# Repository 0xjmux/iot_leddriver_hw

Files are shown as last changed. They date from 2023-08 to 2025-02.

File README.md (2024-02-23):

# Spotify Neopixel Visualizer Hardware
Simple and compact ESP32-based WS2812B LED Strip Driver.   

<p align="center">
  
</p>

<!-- * Board firmware (in progress, not yet published) will be eventually available at [iot_leddriver_sw](https://github.com/0xjmux/iot_leddriver_sw). -->
* Origianlly planned to design my own firmware to integrate with the Spotify API Directly; but eventually switched to the much more featured combination of WLED + LEDFx. 
* Compatible with the popular [WLED](https://github.com/Aircoookie/WLED) firmware: just change the LED data pin to `GPIO21`. 
* (See [DEVELOPMENT-NOTES.md](DEVELOPMENT-NOTES.md) for full pinout and other information).

> [!WARNING]
> This was my first real PCB design, and I've improved a lot since I completed it. Take it (especially <=v2.2) with a grain of salt. 
 
### Features
* ESP32 based for low-cost IoT Capability, can use either `ESP32-S2-SOLO` (single core, cheaper) or `ESP32-S3-WROOM` (dual core). 
* Programmable over USB C, with Tag-Connect JTAG header for full debug capability. 
* Two ways to attach LED strip, either via pin header or with a strain relief. 
* Board designed to drive a 5m 60LED/m WS2812B strip with safety marign (see [DEVELOPMENT-NOTES.md](DEVELOPMENT-NOTES.md))
* Entirely LCSC BOM, designed for both hand and machine assembly. Able to be assembled by JLCPCB with low-cost components (almost all basic component BOM).

##### Optional Features and Mounting
* Designed to also be capable of driving 12V strips like the WS2811; only modification needed is changing the 5V overvoltage protection diodes (`D1`&`D2`, PN `SMF5V0A`) to 12V diodes (like `SMF12A`s)
* M2 mounting holes, various test pads, and an emergency UART header on the bottom. 
* Includes I2C breakout for optional addition of SSD1306 OLED.
* MEMS Microphone can optionally be added for live sound reactivity. 

#### Update 1/2024 - Now with a 3D Printable case!
* Check out [case/](./case/) for the 3D printable case I designed! This is the result of my first design using CAD in a very long time, and while it has some things I would change now I think it's still probably better published than not. 
* A PDF drawing of the case with dimensions can be found [here](case/iot_leddriver_drawing_v0.5.pdf).

<p align="center">
IRL picture of installation. Don't judge, it's in a really hard to reach place.
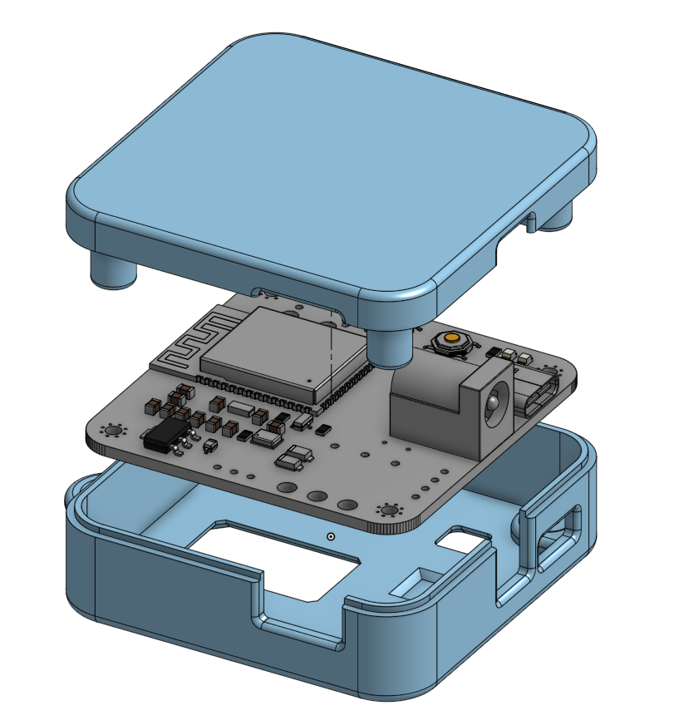
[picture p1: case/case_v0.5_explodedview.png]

</p>

## Notes and Usage
* Schematic, BOM, Gerbers, and all other files needed for production and assembly can be found attached to the latest [release!](https://github.com/0xjmux/iot_leddriver_hw/releases/latest)
  * This includes an interactive HTML BOM, which makes hand assembly much easier. 
* View current layout and schematic live on [KiCanvas](https://kicanvas.org/?github=https%3A%2F%2Fgithub.com%2F0xjmux%2Fiot_leddriver_hw%2Ftree%2Fmain%2FPCB)

<p align="center">
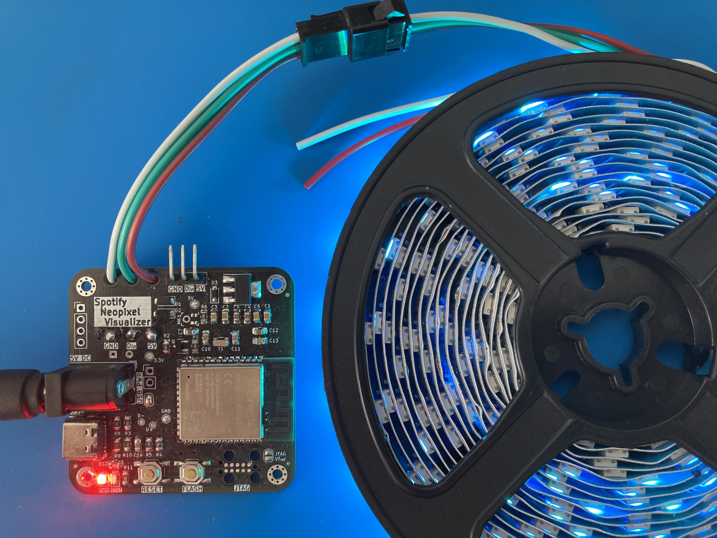
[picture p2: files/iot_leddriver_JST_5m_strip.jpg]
v2.1 showing LED strip standard JST connector connected to 5M WS2812B strip
  
<br>v2.1 showing LED strip standard JST connector connected to 5M WS2812B strip
</p>

## Versions
### V2.2 - QoL and Improvements for Production
* Mostly minor updates, to bring the board up to a more "production" ready state. Some modifications/fixes for small things found during manual assembly. 
* Power trace width from USB C port increased so short lengths of strip can be driven directly from USB.
* Traces cleaned up, PWR_LED can now be disconnected (if it's going to be deployed somewhere and the constant light is unwanted). USB_PWR jumpers removed. 
* BOM consolidation, some notes added to schematic, documentation improvements. 

<p align="center">
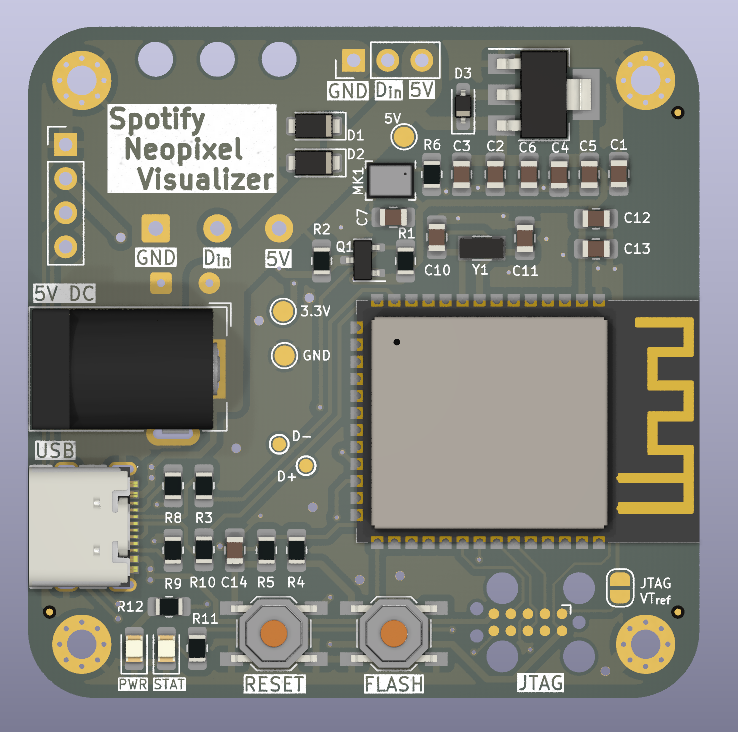
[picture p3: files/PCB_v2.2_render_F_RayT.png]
v2.2 PCB Render Front

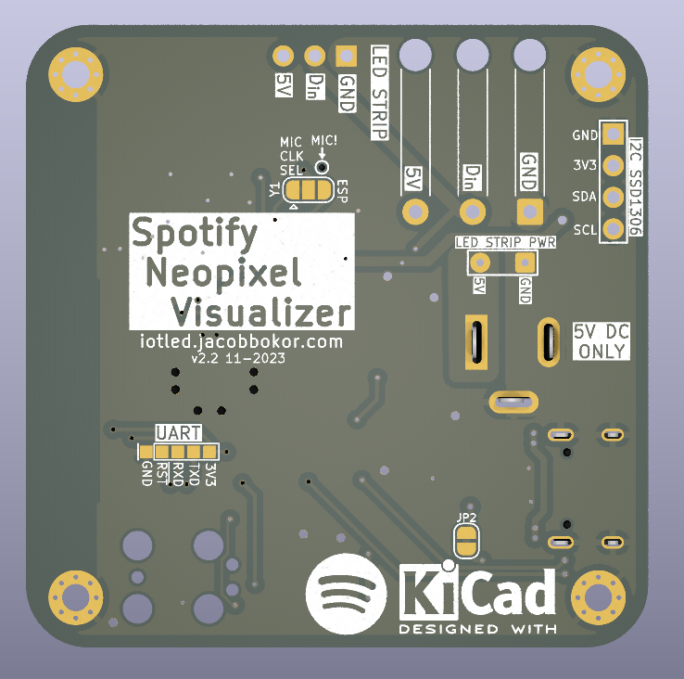
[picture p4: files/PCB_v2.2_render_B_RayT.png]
v2.2 PCB Render Back

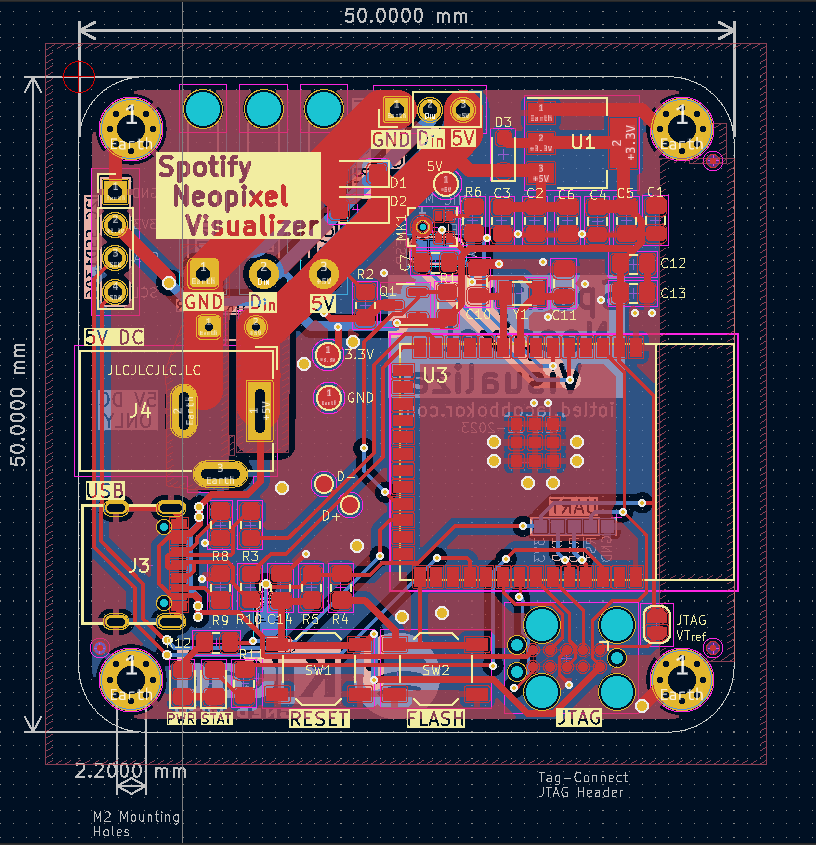
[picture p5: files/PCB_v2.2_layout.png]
v2.2 PCB Layout

</p>

### V2.1 - Hand Assembleable
* MCU originally selected for V2, the `ESP32-S2-MINI`, wasn't hand assemble-able; so it's been replaced with an `ESP32-S2-SOLO`. 
* Various small upgrades, including removal of non-necessary RC components, a mini UART header, and additional 5V power lines right next to the 2.1mm jack for strips with additional power wires. 
* The footprint and supporting components for a MEMS Microphone (`SPH0641LM4H-1`) added in case live sound reactivity is desired later on. 

<p align="center">
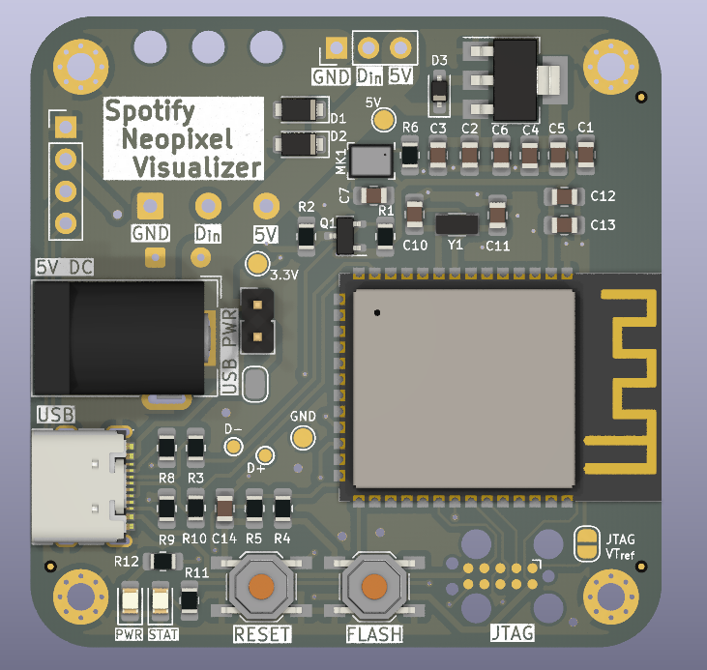
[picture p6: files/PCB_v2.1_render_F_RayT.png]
v2.1 PCB Render Front

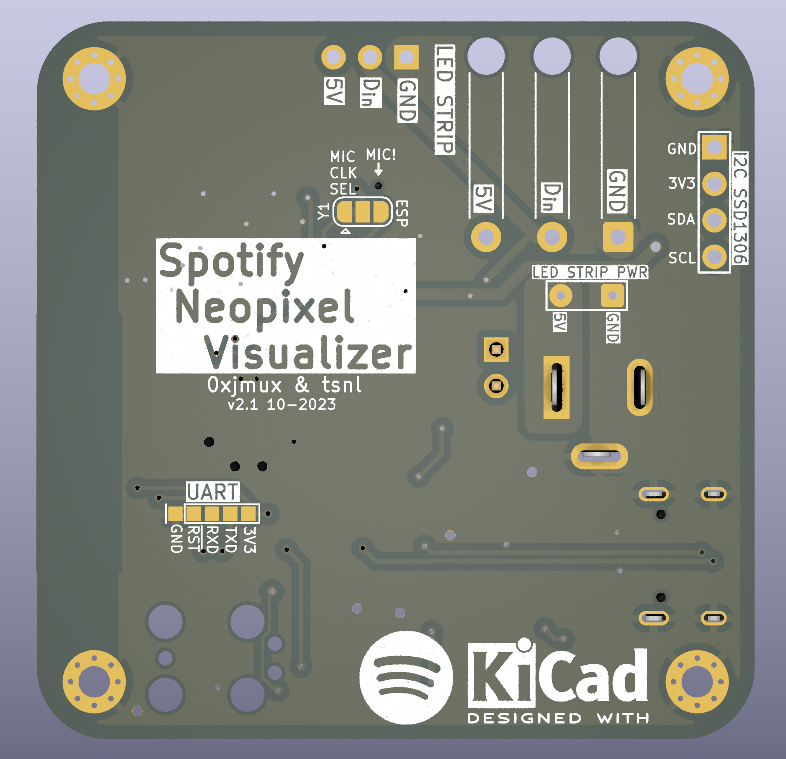
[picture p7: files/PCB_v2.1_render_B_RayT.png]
v2.1 PCB Render Back

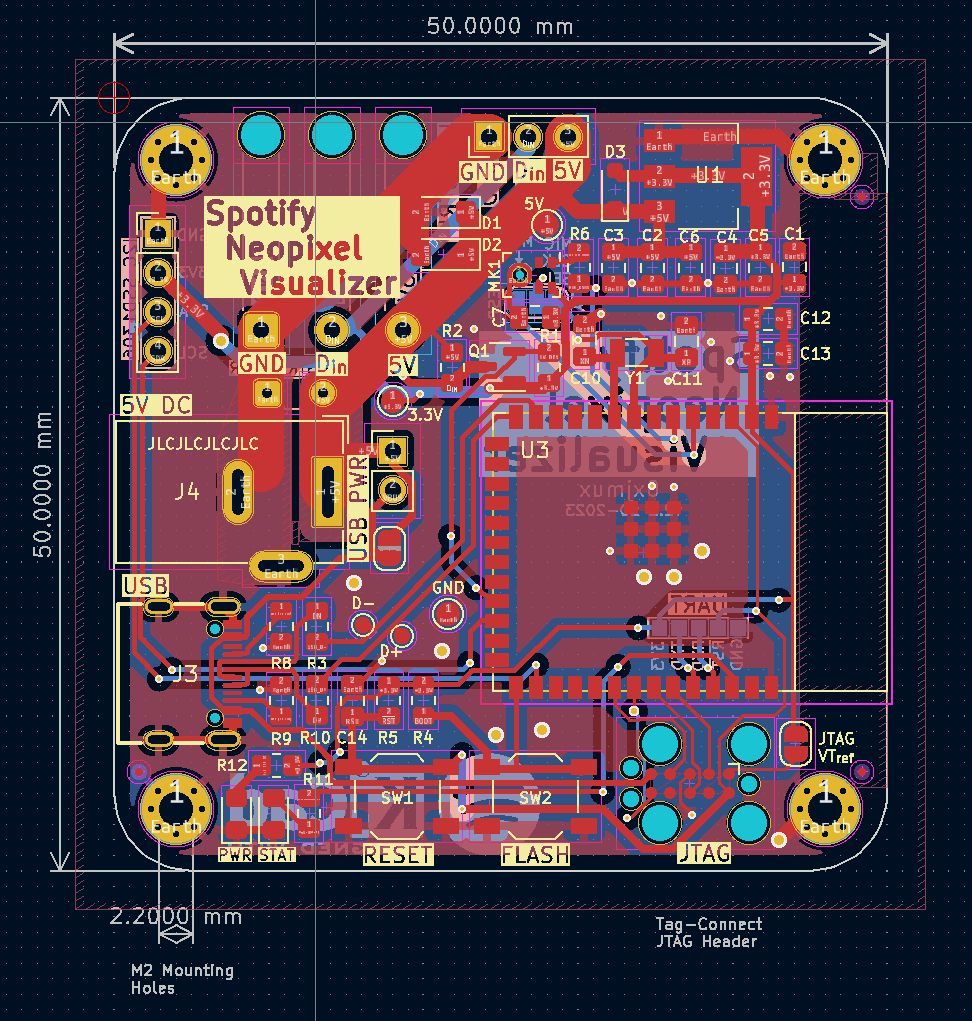
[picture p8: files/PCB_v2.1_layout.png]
v2.1 PCB Layout

</p>

### V2.0 - Complete redesign, now ESP32 Based
* Board upgraded to the `ESP32-S2-MINI-2-N4` for better compute capability, completely redesigned solely around the WS2812B.
* Most of the features listed above were introduced in this version.

<p align="center">
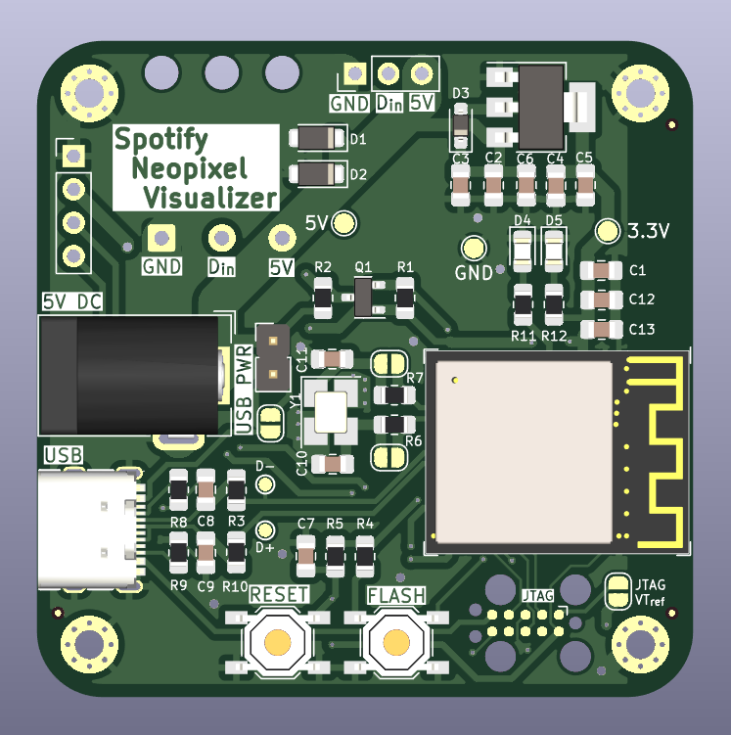
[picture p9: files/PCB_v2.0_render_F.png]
v2.0 PCB Render Front

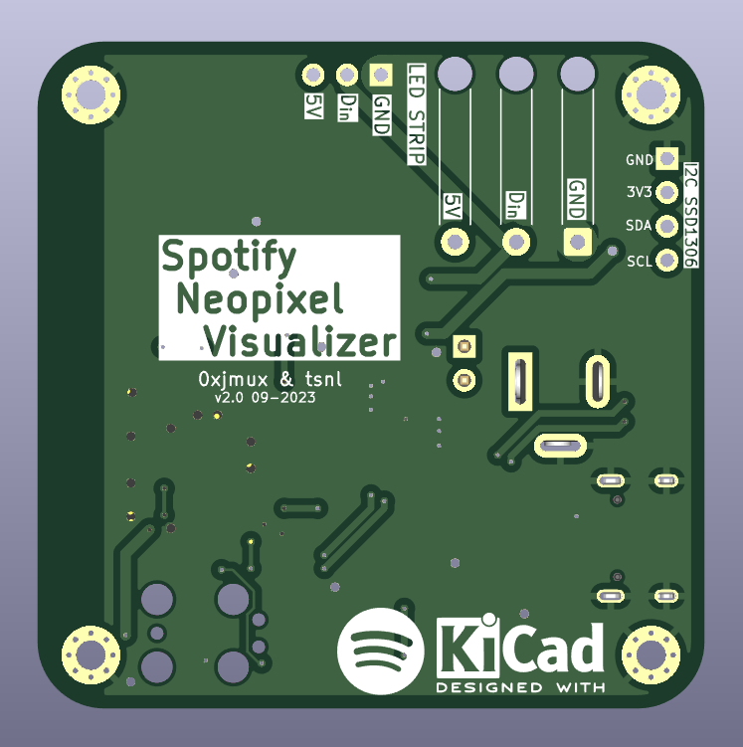
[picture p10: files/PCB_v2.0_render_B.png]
v2.0 PCB Render Back

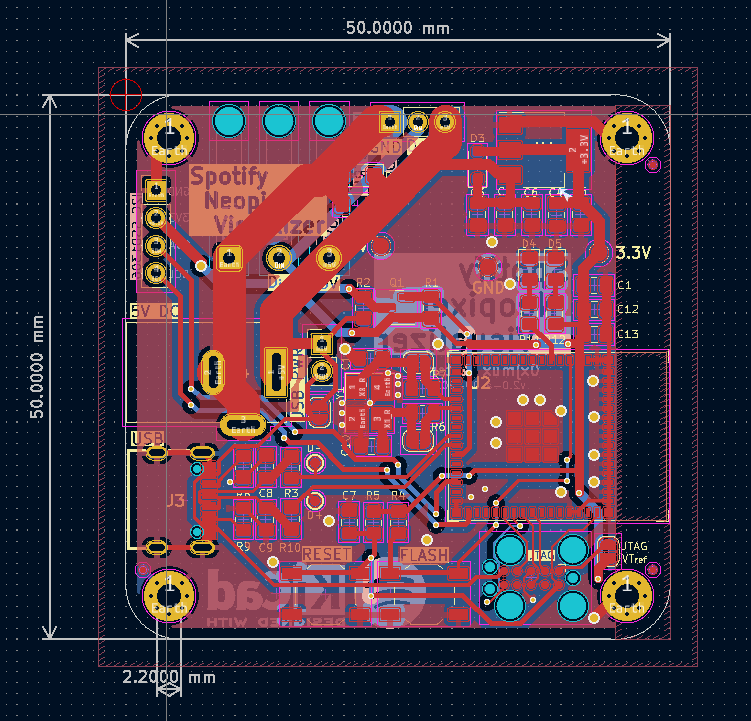
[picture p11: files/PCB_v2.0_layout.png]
v2.0 PCB Layout

</p>

---
### V1.0 Prototype
* [Link to v1.0 branch](https://github.com/0xjmux/iot_leddriver_hw/tree/v1.0)
* V1.0 was an IoT enabled LED strip driver using ESP8266 capable of using both WS2812B (Neopixel) and standard 5050 12V LED strips. Goal is to integrate with the spotify API to allow color changes in reaction to music. 
* V1 was never fully tested; right as v1.0 was ready my goal with the project shifted, and the ESP82666 just doesn't have enough compute for what I wanted to do. 
* If board will only be used in 5V (neopixel) mode, then the 3 `UMW30N06` Mosfets and 2 of the `MCP1416` mosfet drivers are not needed. Additionally, if the board will only be run in one mode then the unused 2.1mm jack does not need to be installed. 
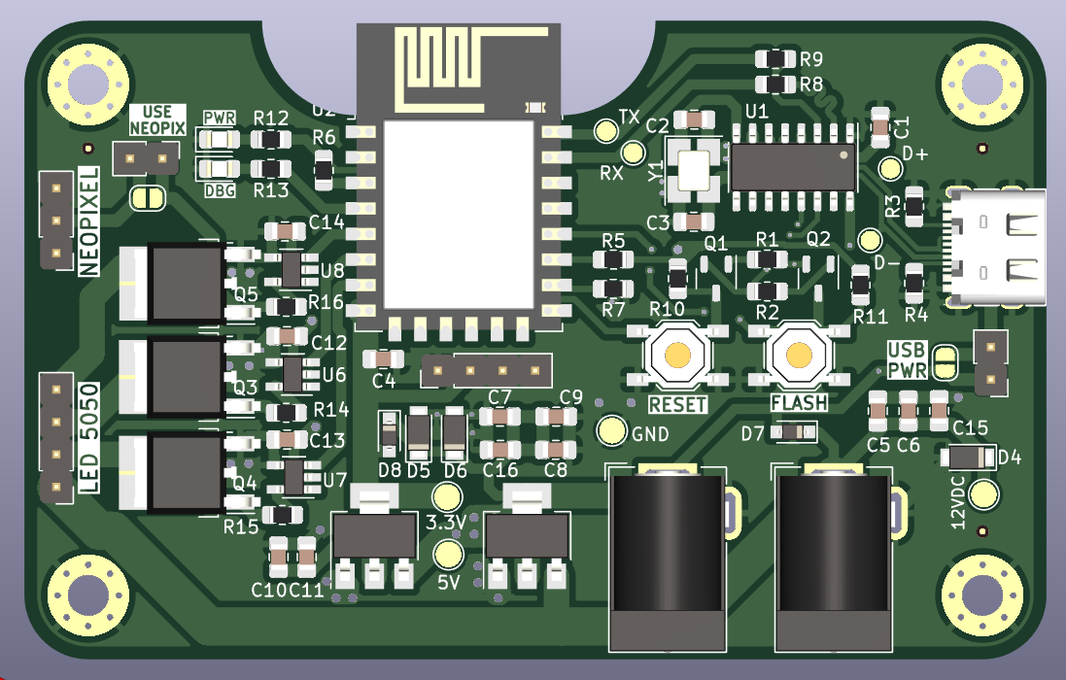
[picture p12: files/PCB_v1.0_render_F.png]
v1 PCB Render Front

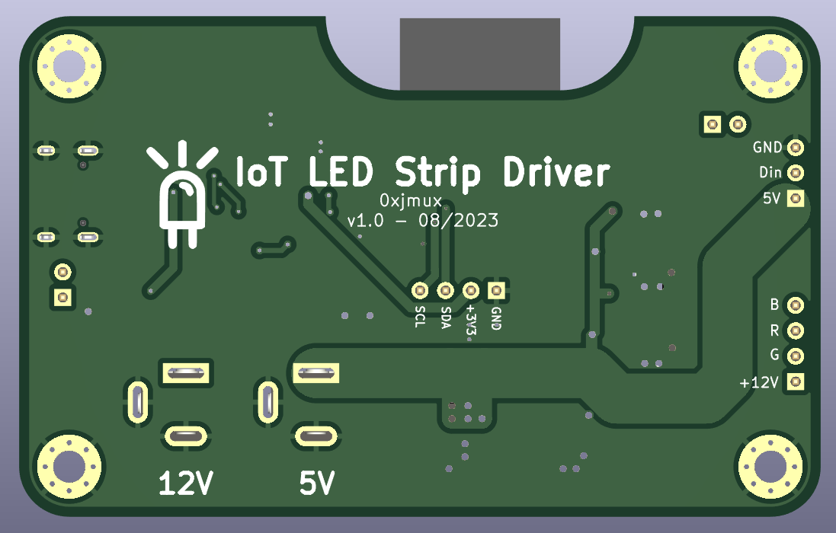
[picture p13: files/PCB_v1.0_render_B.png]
v1 PCB Render Back

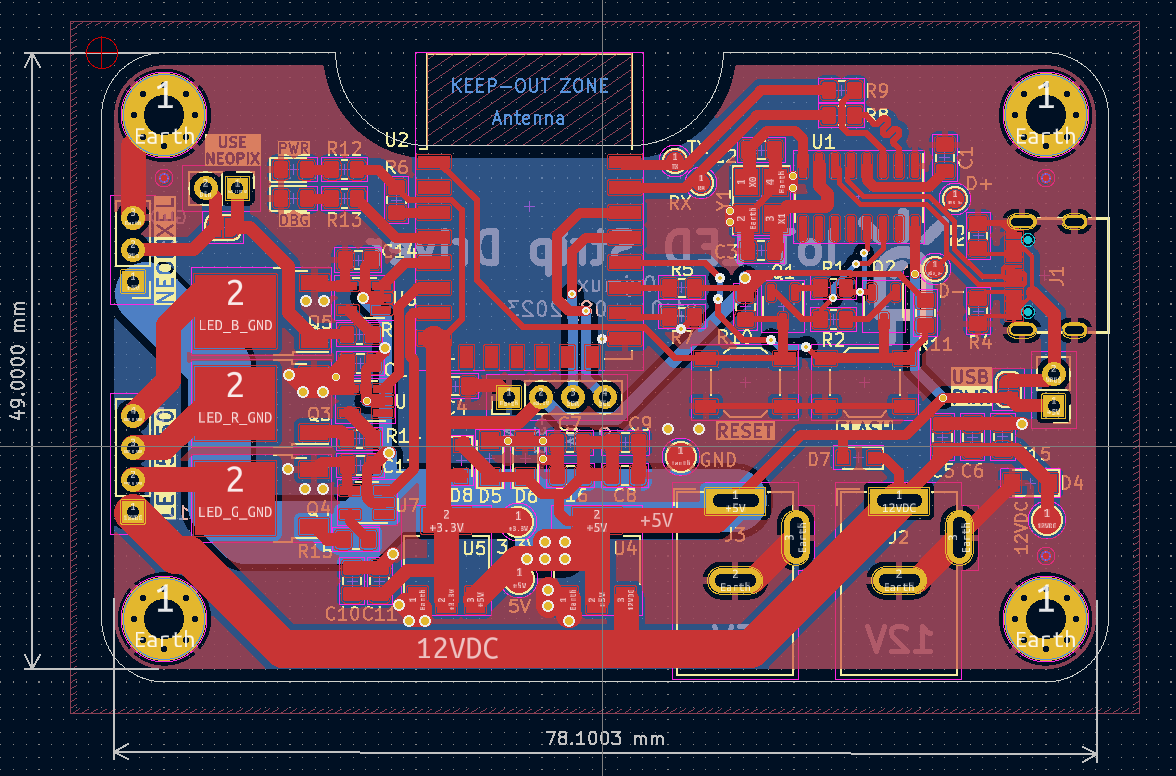
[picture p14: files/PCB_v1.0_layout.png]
v1 PCB Layout


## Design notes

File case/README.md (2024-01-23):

### Case info
* It's designed to be printed in PLA with 10% infill, and is held together by M2x8mm bolts. 
* The bolts are self tapping, and while I was originally planning on heat-set the self-tapped threads work so well that I'm just going to leave them as-is. 
* I included two different bottom models: One has a screwtab for easy mounting, and the other doesn't. You only need one. 

<p align="center">
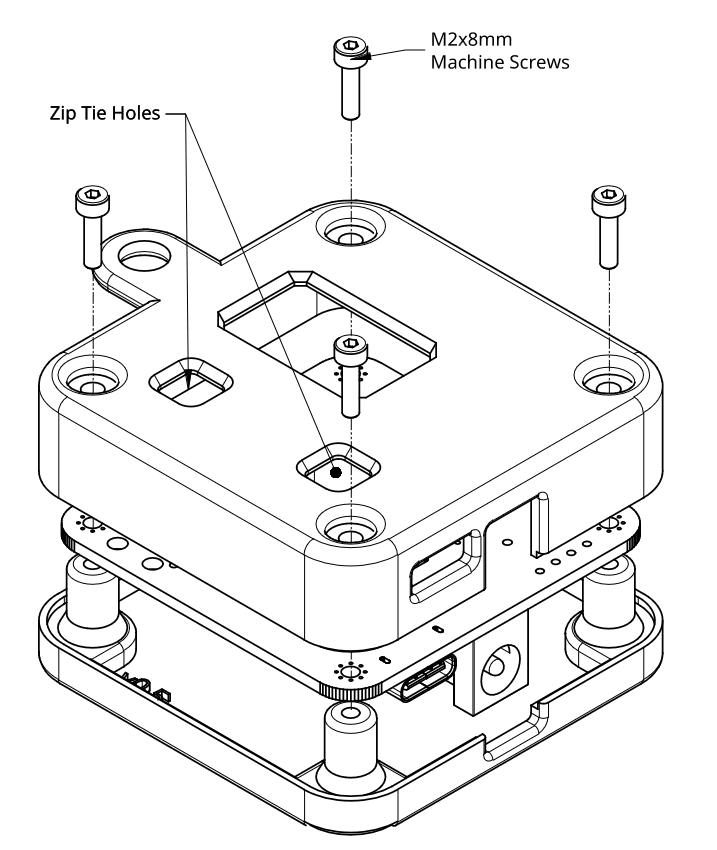
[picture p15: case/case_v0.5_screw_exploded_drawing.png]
  
  
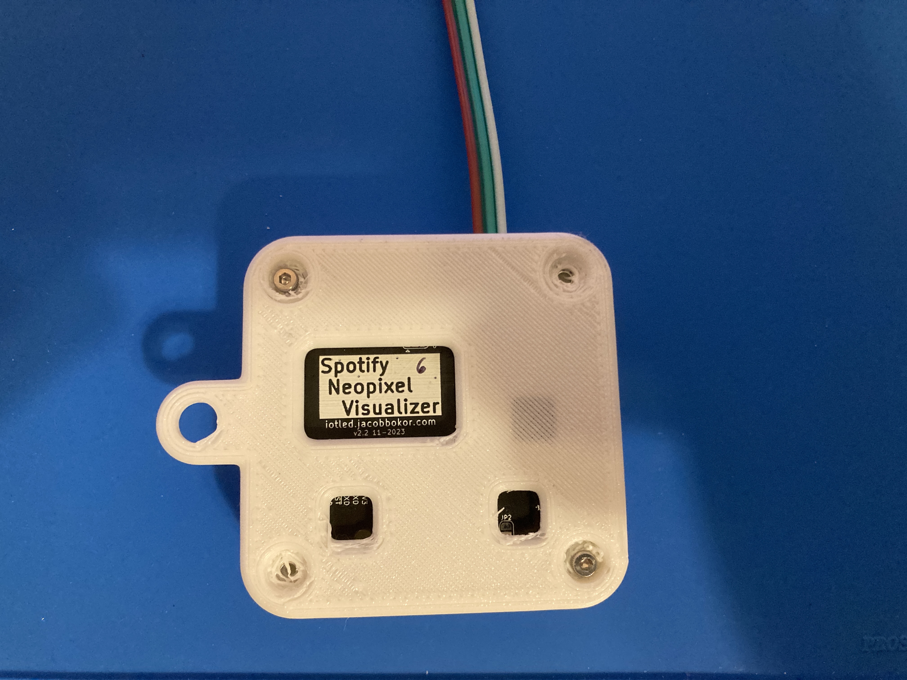
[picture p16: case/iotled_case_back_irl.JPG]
  
</p>

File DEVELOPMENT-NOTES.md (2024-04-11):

## Important Design Information
* All information about the board needed for development can be found attached tothe [latest release](https://github.com/0xjmux/iot_leddriver_hw/releases/latest)
#### Ideas/todo
* tindie listing with PCB and ESP-PROG adapter as like "wled developer kit?"
* 

## V2.2
* Current microcontroller is ESP32-S2-SOLO ([datasheet](https://www.espressif.com/sites/default/files/documentation/esp32-s2-solo-2_esp32-s2-solo-2u_datasheet_en.pdf))
* We're also attempting to use the [ESP32-S3-WROOM-2](https://www.espressif.com/sites/default/files/documentation/esp32-s3-wroom-2_datasheet_en.pdf) microcontroller during development, because of its dual-core capability. 
*  A MEMS Microphone, the `SPH0641LU4H-1`, can be optionally installed in case we later want to add live sound reactivity ([datasheet](https://www.knowles.com/docs/default-source/default-document-library/sph0641lm4h-1-datasheet-rev-f.pdf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) ).
#### Pinout

| GPIO PIN | Connected to |
|---|---|
| `GPIO21` | LED Strip D_in |
| `GPIO2`  | Status LED |
| `GPIO33` | I2C SDA |
| `GPIO35` | I2C SCL |
| `GPIO5`  | MEMS Mic Clock |
| `GPIO6`  | MEMS Mic Data  |

##### V2.2 breaking change:
* From v2.2, SCL has been moved to `GPIO37`. This was because on the WROOM, `GPIO35` is not present (and is an NC pin). 

#### Hardware Limitations
* Trace width and vias for power delivery from DC jack to LED Strip Power lines calculated to handle 12A with ΔT rise of <10°C. 
* Maximum draw of a 5M 60 LED/m WS2812B strip (all white at maximum brightness) is 12A @ 5V. Anything longer than that and you start seeing the brightness drop due to the resistance of the traces inside the strip, so it is unlikely this design limit will be exceeded. 

### ESP32-S2-SOLO Information
* [ESP32-S2-SOLO-2 Datasheet pdf](https://www.espressif.com/sites/default/files/documentation/esp32-s2-solo-2_esp32-s2-solo-2u_datasheet_en.pdf)
* [esp32-s2_hardware_design_guidelines_en.pdf](https://www.espressif.com/sites/default/files/documentation/esp32-s2_hardware_design_guidelines_en.pdf)
* [esp32-s2_technical_reference_manual_en.pdf](https://www.espressif.com/sites/default/files/documentation/esp32-s2_technical_reference_manual_en.pdf)

### ESP32-S3-WROOM Information
What we're using during development, since it's the most powerful ESP32 chip currently available + is dual core. If we don't end up needing the second core, software will be able to be compiled for S2. 
* [ESP32-S3-WROOM-2 Datasheet pdf](https://www.espressif.com/sites/default/files/documentation/esp32-s3-wroom-2_datasheet_en.pdf)

### ESP32 pin information
* [ESP32 Pinout Reference: Which GPIO pins should you use? | Random Nerd Tutorials](https://randomnerdtutorials.com/esp32-pinout-reference-gpios/)

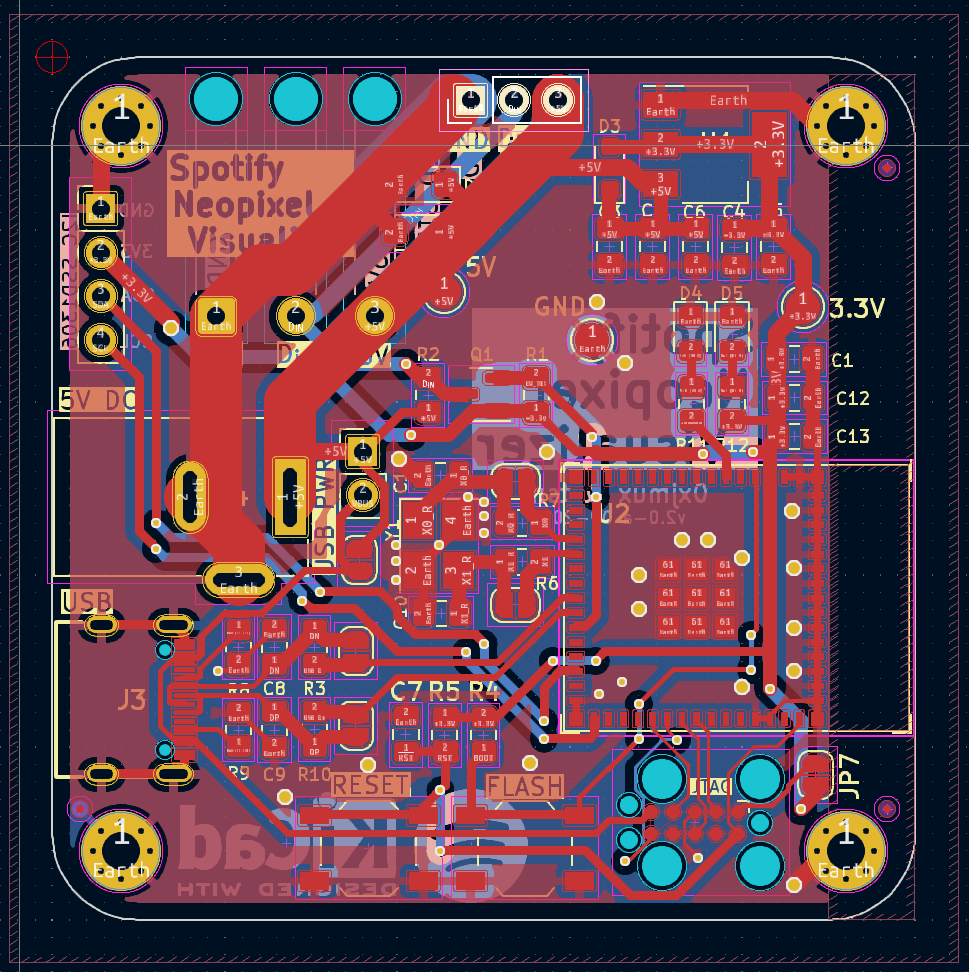
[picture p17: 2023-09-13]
files/PCB_v1.9.1-a_layout.png

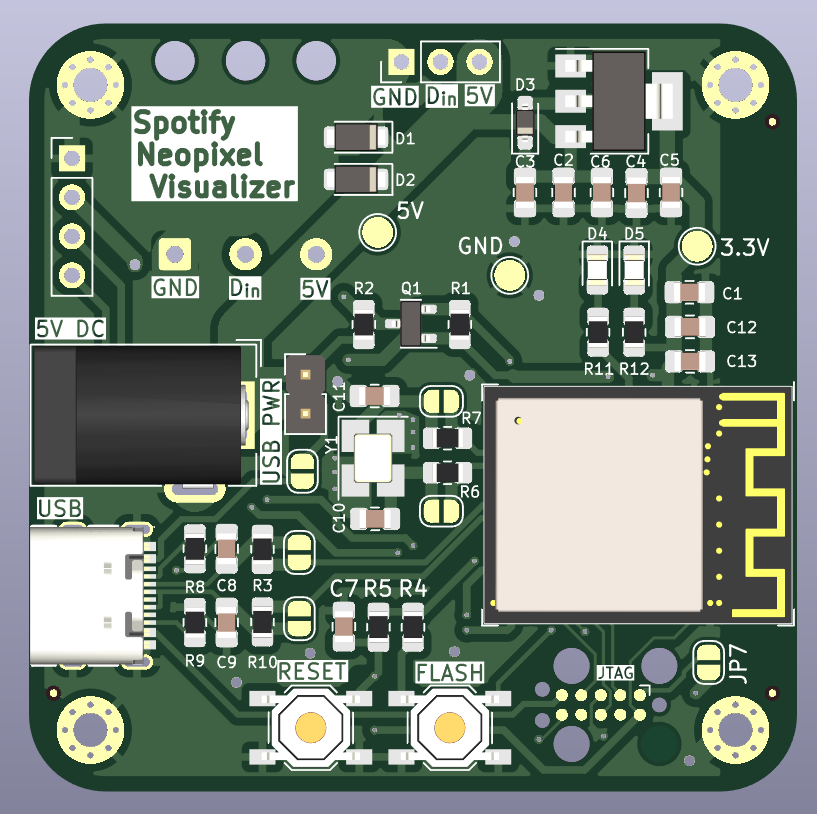
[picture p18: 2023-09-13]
files/PCB_v1.9.1-a_render_F.png

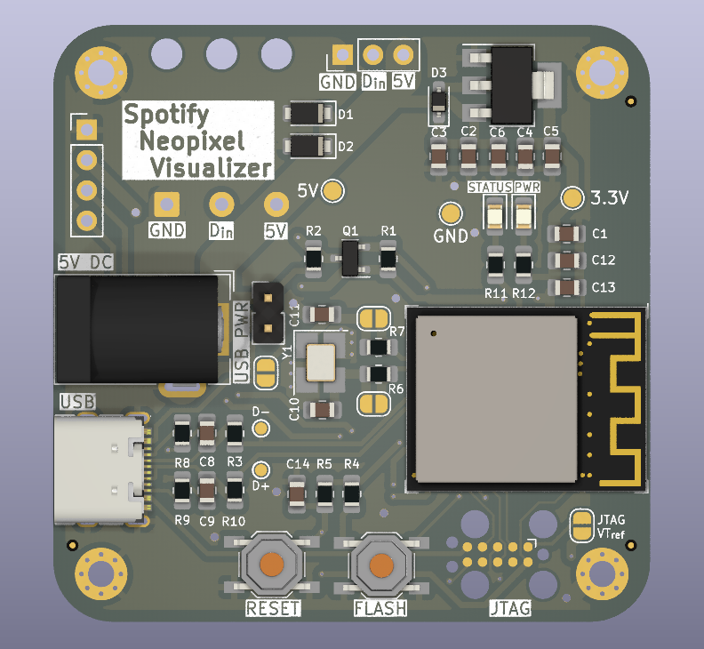
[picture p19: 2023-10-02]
files/PCB_v2.0.1-render_F_RayT.png

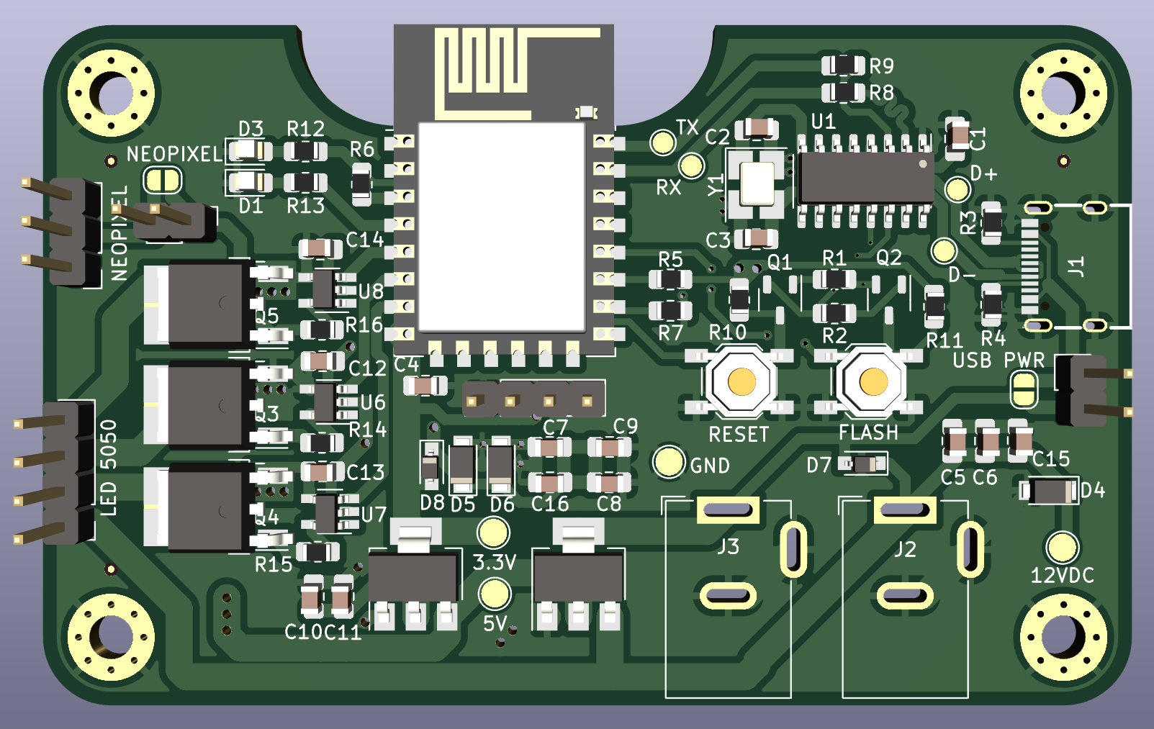
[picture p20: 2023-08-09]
files/PCB_v0.9.1_render_F.png

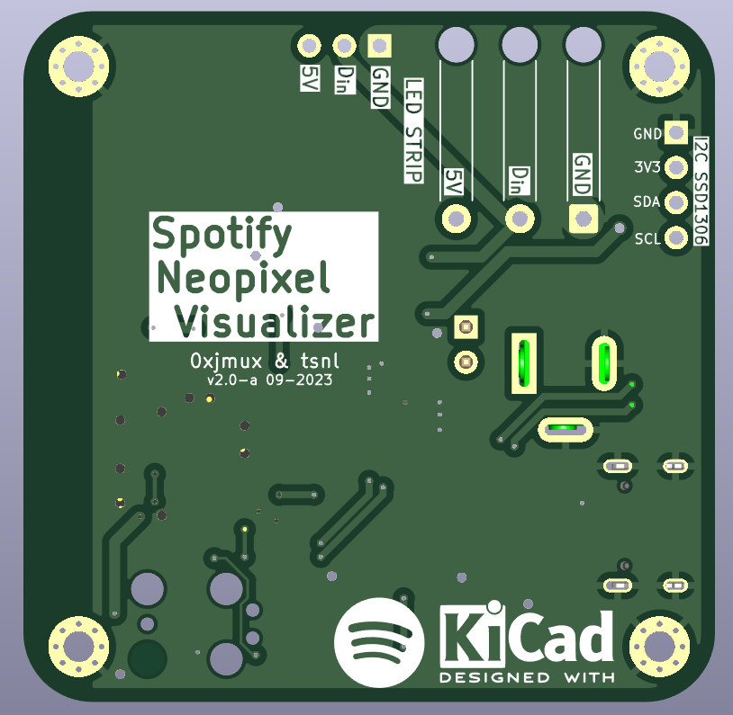
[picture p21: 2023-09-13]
files/PCB_v1.9.1-a_render_B.png

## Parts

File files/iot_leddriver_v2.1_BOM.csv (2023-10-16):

Source: | /home/jmux/Github/spotify-iot-led-driver/iot_leddriver_hw/iot_led_strip_pcb.kicad_sch
Date: | Sun 15 Oct 2023 09:47:59 PM PDT
Tool: | Eeschema 7.0.7-2.fc37
Generator: | /usr/share/kicad/plugins/bom_csv_grouped_by_value.py
Component Count: | 37
Collated Components:
Item | Qty | Reference(s) | Value | LibPart | Footprint | Datasheet | DNP | Description | LCSC | Sim.Device | Sim.Params | Sim.Pins | Sim.Type | Vendor
1 | 5 | C1, C2, C3, C5, C13 | 10uF | Device:C | Capacitor_SMD:C_0805_2012Metric_Pad1.18x1.45mm_HandSolder | ~ |  | 16V 10uF 0805 Ceramic Capacitor SMD | C15850 |  |  |  |  | https://www.lcsc.com/product-detail/Multilayer-Ceramic-Capacitors-MLCC-SMD-SMT_Murata-Electronics-GRM21BR61C106KE15L_C77075.html
2 | 5 | C4, C6, C7, C12, C14 | 100nF | Device:C | Capacitor_SMD:C_0805_2012Metric_Pad1.18x1.45mm_HandSolder | ~ |  | 100nF 50V X7R ±10% 0805 Ceramic Cap SMD | C49678 |  |  |  |  | https://jlcpcb.com/partdetail/Yageo-CC0805KRX7R9BB104/C49678
3 | 2 | C10, C11 | 22pF | Device:C | Capacitor_SMD:C_0805_2012Metric_Pad1.18x1.45mm_HandSolder | ~ |  | 22pF 50V ±5% 0805 Multilayer Ceramic Capacitors | C1804 |  |  |  |  | https://www.lcsc.com/product-detail/Multilayer-Ceramic-Capacitors-MLCC-SMD-SMT_FH-Guangdong-Fenghua-Advanced-Tech-0805CG220J500NT_C24658.html
4 | 2 | D1, D2 | SMF5V0A | Diode:SMF5V0A | Diode_SMD:D_SMF | https://www.vishay.com/doc?85881 |  | 9.2V 6.4V 5V SMF TVS | C1972946
5 | 1 | D3 | 1N5819WS | Device:D_Schottky | Diode_SMD:D_SOD-323_HandSoldering | ~ |  | 40V 600mV@1A 1A SOD-323 Schottky Barrier Diode | C191023
6 | 1 | D4 | STAT | Device:LED | LED_SMD:LED_0805_2012Metric_Pad1.15x1.40mm_HandSolder | ~ |  | Blue (red linked) 0805 Light Emitting Diode | C84256 |  |  |  |  | https://www.lcsc.com/product-detail/Light-Emitting-Diodes-LED_Foshan-NationStar-Optoelectronics-NCD1206B1_C130717.html
7 | 1 | D5 | PWR | Device:LED | LED_SMD:LED_0805_2012Metric_Pad1.15x1.40mm_HandSolder | ~ |  | Red 0805 Light Emitting Diode | C84256 |  |  |  |  | https://www.lcsc.com/product-detail/Light-Emitting-Diodes-LED_Foshan-NationStar-Optoelectronics-NCD1206B1_C130717.html
8 | 1 | J3 | GT-USB-7010ASV | gt-usb_lib:GT-USB-7010ASV | footprint:USB-C-SMD_G-SWITCH_GT-USB-7010ASV | https://atta.szlcsc.com/upload/public/pdf/source/20220407/8043DBBC37E1BDE9D4FD36EE7A4A9BB9.pdf |  |  | C2988369 |  |  |  |  | https://www.lcsc.com/product-detail/USB-Connectors_G-Switch-GT-USB-7010ASV_C2988369.html
9 | 1 | J4 | Barrel_Jack_Switch_Pin3Ring | Connector:Barrel_Jack_Switch_Pin3Ring | Connector_BarrelJack:BarrelJack_Wuerth_6941xx301002 | ~ |  |  |  | V | dc=5 | 1=+ 2=- | DC
10 | 1 | MK1 | SPH0641LU4H-1 | Sensor_Audio:SPH0641LU4H-1 | Sensor_Audio:Knowles_LGA-5_3.5x2.65mm | https://www.knowles.com/docs/default-source/model-downloads/sph0641lu4h-1-revb.pdf |  | MEMS Microphone. COVER HOLE DURING ASSEMBLY!!! | C5454543 |  |  |  |  | https://www.lcsc.com/product-detail/MEMS-Microphones_Knowles-SPH0641LM4H-1-8_C5454543.html
11 | 1 | Q1 | BSS138 | Transistor_FET:BSS138 | Package_TO_SOT_SMD:SOT-23 | https://www.onsemi.com/pub/Collateral/BSS138-D.PDF |  | 50V 220mA 3.5Ω@10V,220mA 360mW N Channel SOT-23(TO-236) MOSFET | C358381 |  |  |  |  | https://jlcpcb.com/partdetail/Foshan_Blue_RocketElec-BSS138/C358381
12 | 4 | R1, R2, R4, R5 | 10k | Device:R_US | Resistor_SMD:R_0805_2012Metric_Pad1.20x1.40mm_HandSolder | ~ |  | 10kΩ 0805 Chip Resistor | C17414 |  |  |  |  | https://www.lcsc.com/product-detail/Chip-Resistor-Surface-Mount_FOJAN-FRQ0805F1002TS_C5159708.html
13 | 2 | R3, R10 | 27R | Device:R_US | Resistor_SMD:R_0805_2012Metric_Pad1.20x1.40mm_HandSolder | ~ |  | 27Ω 0805 125mW Chip Resistor | C17594 |  |  |  |  | https://www.lcsc.com/product-detail/Chip-Resistor-Surface-Mount_UNI-ROYAL-Uniroyal-Elec-0805W8F270JT5E_C17594.html
14 | 3 | R6, R11, R12 | 100 | Device:R_US | Resistor_SMD:R_0805_2012Metric_Pad1.20x1.40mm_HandSolder | ~ |  | 100Ω 0805 125mW Chip Resistor | C17408 |  |  |  |  | https://jlcpcb.com/partdetail/18096-0805W8F1000T5E/C17408
15 | 2 | R8, R9 | 5.1k | Device:R_US | Resistor_SMD:R_0805_2012Metric_Pad1.20x1.40mm_HandSolder | ~ |  | 5.1kΩ 0805 125mW Chip Resistor | C27834 |  |  |  |  | https://www.lcsc.com/product-detail/Chip-Resistor-Surface-Mount_VO-0805-5-470_C2889528.html
16 | 1 | SW1 | RESET | C5117870_lib:GT-TC060A-H025-L1 | Button_Switch_SMD:SW_SPST_TL3342 | https://item.szlcsc.com/902766.html |  |  | C318884 |  |  |  |  | https://www.lcsc.com/product-detail/Tactile-Switches_G-Switch-GT-TC060A-H025-L1_C5117870.html
17 | 1 | SW2 | FLASH | C5117870_lib:GT-TC060A-H025-L1 | Button_Switch_SMD:SW_SPST_TL3342 | https://item.szlcsc.com/902766.html |  |  | C318884 |  |  |  |  | https://www.lcsc.com/product-detail/Tactile-Switches_G-Switch-GT-TC060A-H025-L1_C5117870.html
18 | 1 | U1 | AMS1117-3.3 | Regulator_Linear:AMS1117-3.3 | Package_TO_SOT_SMD:SOT-223-3_TabPin2 | http://www.advanced-monolithic.com/pdf/ds1117.pdf |  |  | C6186 |  |  |  |  | https://www.lcsc.com/product-detail/Linear-span-style-background-color-ff0-Voltage-span-Regulators-LDO_UMW-Youtai-Semiconductor-Co-Ltd-AMS1117-3-3_C347222.html
19 | 1 | U3 | ESP32-S2-SOLO | PCM_Espressif:ESP32-S2-SOLO | Espressif:ESP32-S2-SOLO | https://www.espressif.com/sites/default/files/documentation/esp32-s2-solo_esp32-s2-solo-u_datasheet_en.pdf |  |  | C3040594
20 | 1 | Y1 | Crystal 32kHz | Device:Crystal | Crystal:Crystal_SMD_3215-2Pin_3.2x1.5mm | ~ |  |  | C97606

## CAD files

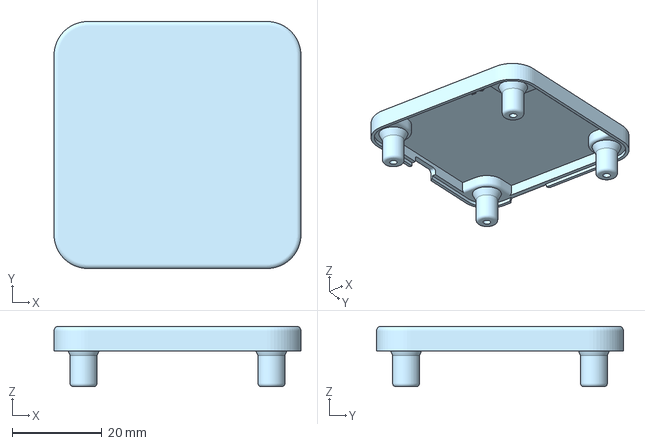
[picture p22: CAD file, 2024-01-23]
case/iot_leddriver_top_v0.5.3mf
55.2 x 55.2 x 13.5 mm

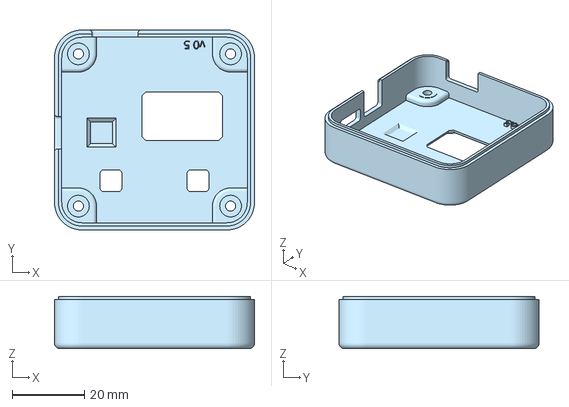
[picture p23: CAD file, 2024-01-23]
case/iot_leddriver_bot_v0.5.3mf
55.2 x 55.2 x 14.4 mm

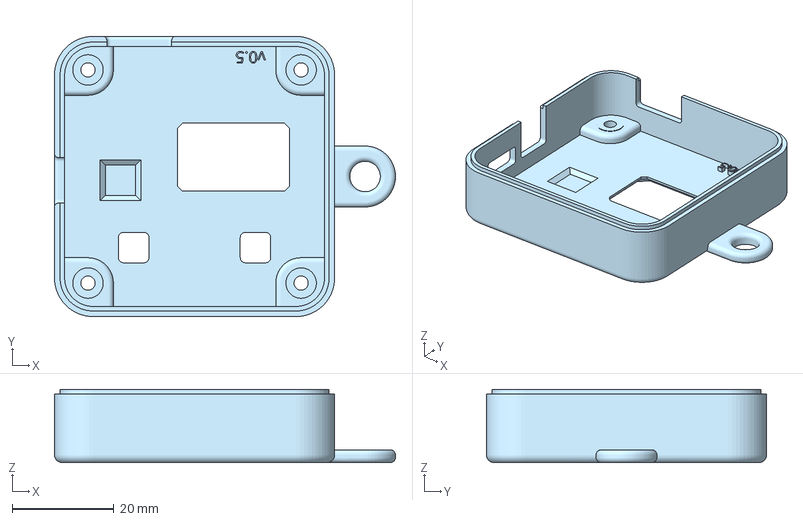
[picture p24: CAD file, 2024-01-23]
case/iot_leddriver_bot_screwtab_v0.5.3mf
67.2 x 55.2 x 14.4 mm

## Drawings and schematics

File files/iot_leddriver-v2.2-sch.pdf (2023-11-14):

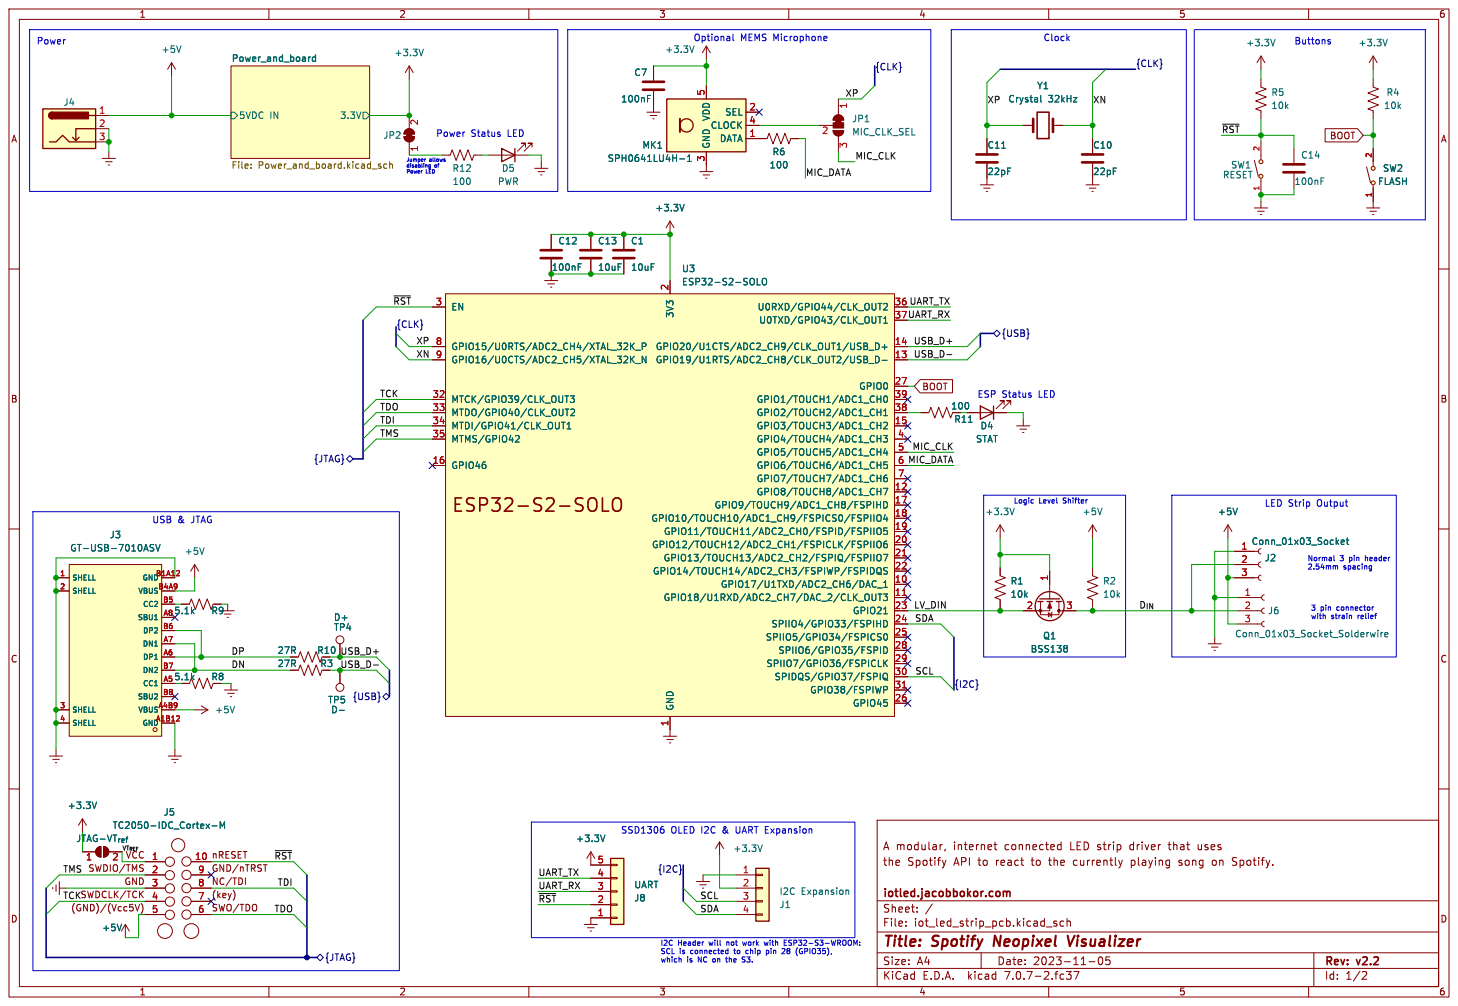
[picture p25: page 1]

2 GPIO12/TOUCH12/ADC2_CH1/FSPICLK/FSPIIO6 20 GPIO13/TOUCH13/ADC2_CH2/FSPIQ/FSPIIO7 21 GPIO14/TOUCH14/ADC2_CH3/FSPIWP/FSPIDQS 22 GPIO21 23 SPIIO4/GPIO33/FSPIHD 24 SPIIO5/GPIO34/FSPICS0 25 GPIO45 26 GPIO0 27 SPIIO6/GPIO35/FSPID 28 SPIIO7/GPIO36/FSPICLK 29 EN 3 SPIDQS/GPIO37/FSPIQ 30 GPIO38/FSPIWP 31 MTCK/GPIO39/CLK_OUT3 32 MTDO/GPIO40/CLK_OUT2 33 MTDI/GPIO41/CLK_OUT1 34 MTMS/GPIO42 35 U0RXD/GPIO44/CLK_OUT2 36 U0TXD/GPIO43/CLK_OUT1 37 GPIO2/TOUCH2/ADC1_CH1 38 GPIO1/TOUCH1/ADC1_CH0 39 GPIO4/TOUCH4/ADC1_CH3 4 GPIO5/TOUCH5/ADC1_CH4 5 GPIO6/TOUCH6/ADC1_CH5 6 GPIO7/TOUCH7/ADC1_CH6 7 GPIO15/U0RTS/ADC2_CH4/XTAL_32K_P 8 GPIO16/U0CTS/ADC2_CH5/XTAL_32K_N 9 U3ESP32-S2-SOLO

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

3 pin connector with strain relief USB & JTAG

iotled.jacobbokor.com
Id: 1/2 Title: Spotify Neopixel Visualizer File: iot_led_strip_pcb.kicad_sch Sheet: /

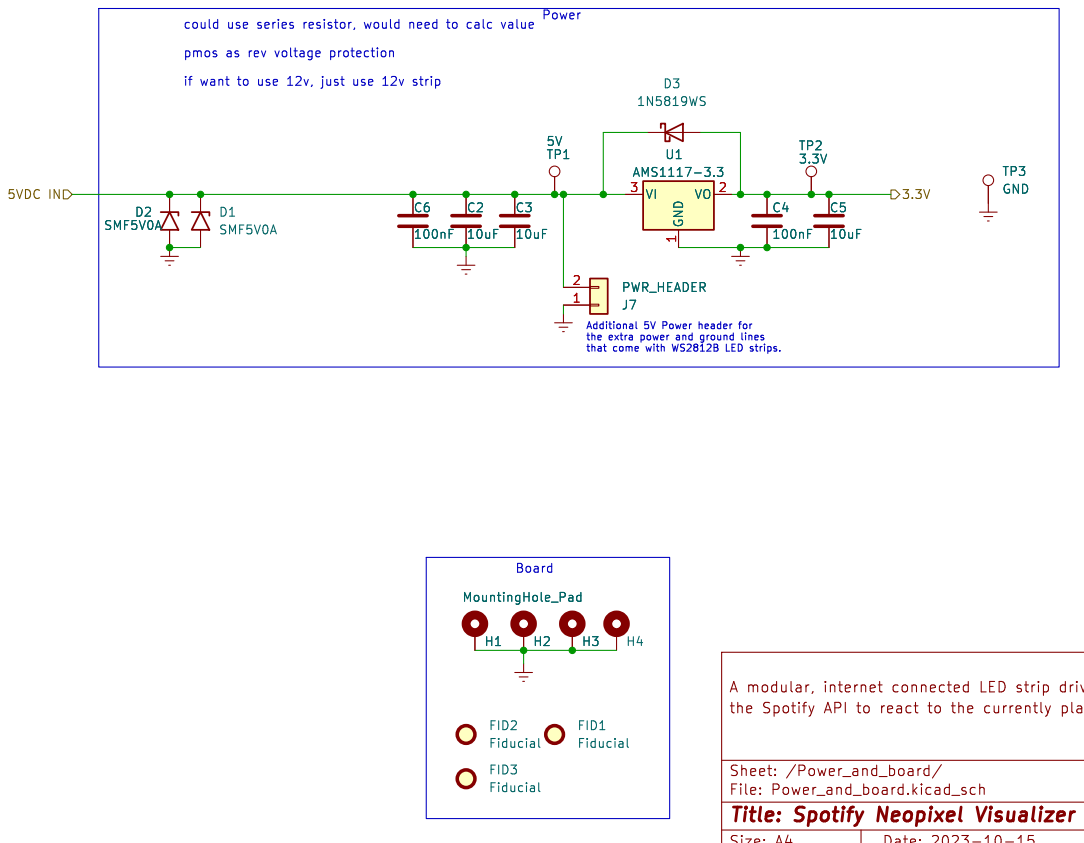
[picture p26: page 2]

pmos as rev voltage protection

1 VO 2 VI 3 U1 AMS1117-3.3 FID2 Fiducial H1 H3 MountingHole_Pad H2 H4 FID1 Fiducial C4

that come with WS2812B LED strips. C3

the extra power and ground lines

Id: 2/2 Title: Spotify Neopixel Visualizer File: Power_and_board.kicad_sch Sheet: /Power_and_board/

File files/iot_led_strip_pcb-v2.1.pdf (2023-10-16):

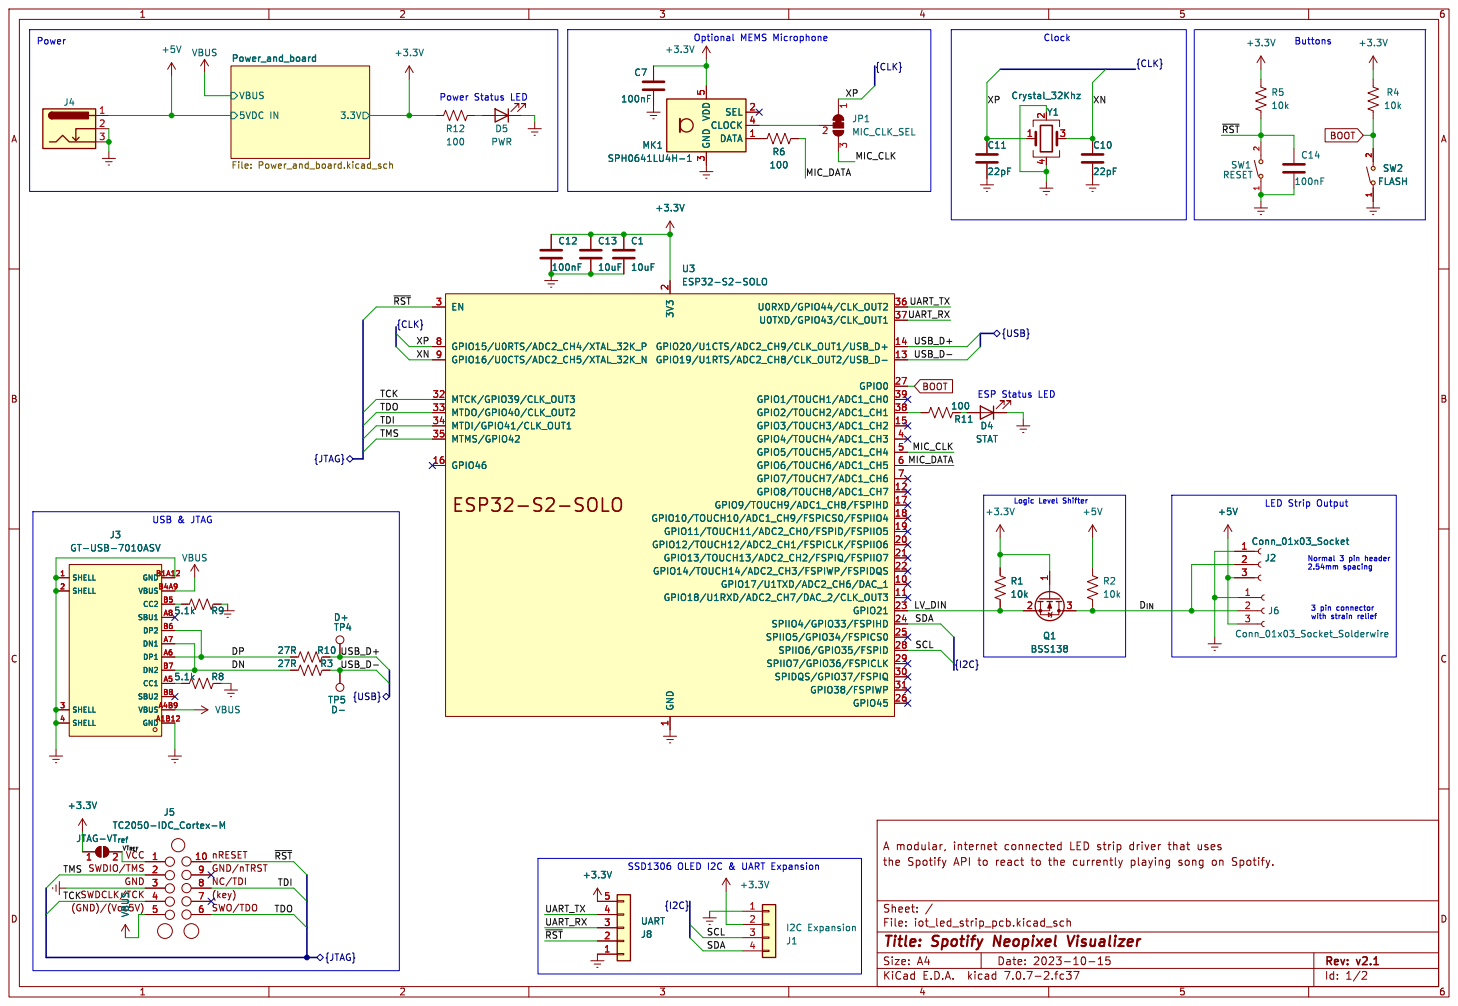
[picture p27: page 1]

2 GPIO12/TOUCH12/ADC2_CH1/FSPICLK/FSPIIO6 20 GPIO13/TOUCH13/ADC2_CH2/FSPIQ/FSPIIO7 21 GPIO14/TOUCH14/ADC2_CH3/FSPIWP/FSPIDQS 22 GPIO21 23 SPIIO4/GPIO33/FSPIHD 24 SPIIO5/GPIO34/FSPICS0 25 GPIO45 26 GPIO0 27 SPIIO6/GPIO35/FSPID 28 SPIIO7/GPIO36/FSPICLK 29 EN 3 SPIDQS/GPIO37/FSPIQ 30 GPIO38/FSPIWP 31 MTCK/GPIO39/CLK_OUT3 32 MTDO/GPIO40/CLK_OUT2 33 MTDI/GPIO41/CLK_OUT1 34 MTMS/GPIO42 35 U0RXD/GPIO44/CLK_OUT2 36 U0TXD/GPIO43/CLK_OUT1 37 GPIO2/TOUCH2/ADC1_CH1 38 GPIO1/TOUCH1/ADC1_CH0 39 GPIO4/TOUCH4/ADC1_CH3 4 GPIO5/TOUCH5/ADC1_CH4 5 GPIO6/TOUCH6/ADC1_CH5 6 GPIO7/TOUCH7/ADC1_CH6 7 GPIO15/U0RTS/ADC2_CH4/XTAL_32K_P 8 GPIO16/U0CTS/ADC2_CH5/XTAL_32K_N 9 C1

2 GPIO12/TOUCH12/ADC2_CH1/FSPICLK/FSPIIO6 20 GPIO13/TOUCH13/ADC2_CH2/FSPIQ/FSPIIO7 21 GPIO14/TOUCH14/ADC2_CH3/FSPIWP/FSPIDQS 22 GPIO21 23 SPIIO4/GPIO33/FSPIHD 24 SPIIO5/GPIO34/FSPICS0 25 GPIO45 26 GPIO0 27 SPIIO6/GPIO35/FSPID 28 SPIIO7/GPIO36/FSPICLK 29 EN 3 SPIDQS/GPIO37/FSPIQ 30 GPIO38/FSPIWP 31 MTCK/GPIO39/CLK_OUT3 32 MTDO/GPIO40/CLK_OUT2 33 MTDI/GPIO41/CLK_OUT1 34 MTMS/GPIO42 35 U0RXD/GPIO44/CLK_OUT2 36 U0TXD/GPIO43/CLK_OUT1 37 GPIO2/TOUCH2/ADC1_CH1 38 GPIO1/TOUCH1/ADC1_CH0 39 GPIO4/TOUCH4/ADC1_CH3 4 GPIO5/TOUCH5/ADC1_CH4 5 GPIO6/TOUCH6/ADC1_CH5 6 GPIO7/TOUCH7/ADC1_CH6 7 GPIO15/U0RTS/ADC2_CH4/XTAL_32K_P 8 GPIO16/U0CTS/ADC2_CH5/XTAL_32K_N 9 U3ESP32-S2-SOLO

Logic Level Shifter SSD1306 OLED I2C & UART Expansion

3 pin connector with strain relief LED Strip Output

JTAG-VT_{ref}VBUS (GND)/(Vcc5V)
~{RST} TCK
SWDIO/TMS

Id: 1/2 Title: Spotify Neopixel Visualizer File: iot_led_strip_pcb.kicad_sch Sheet: /

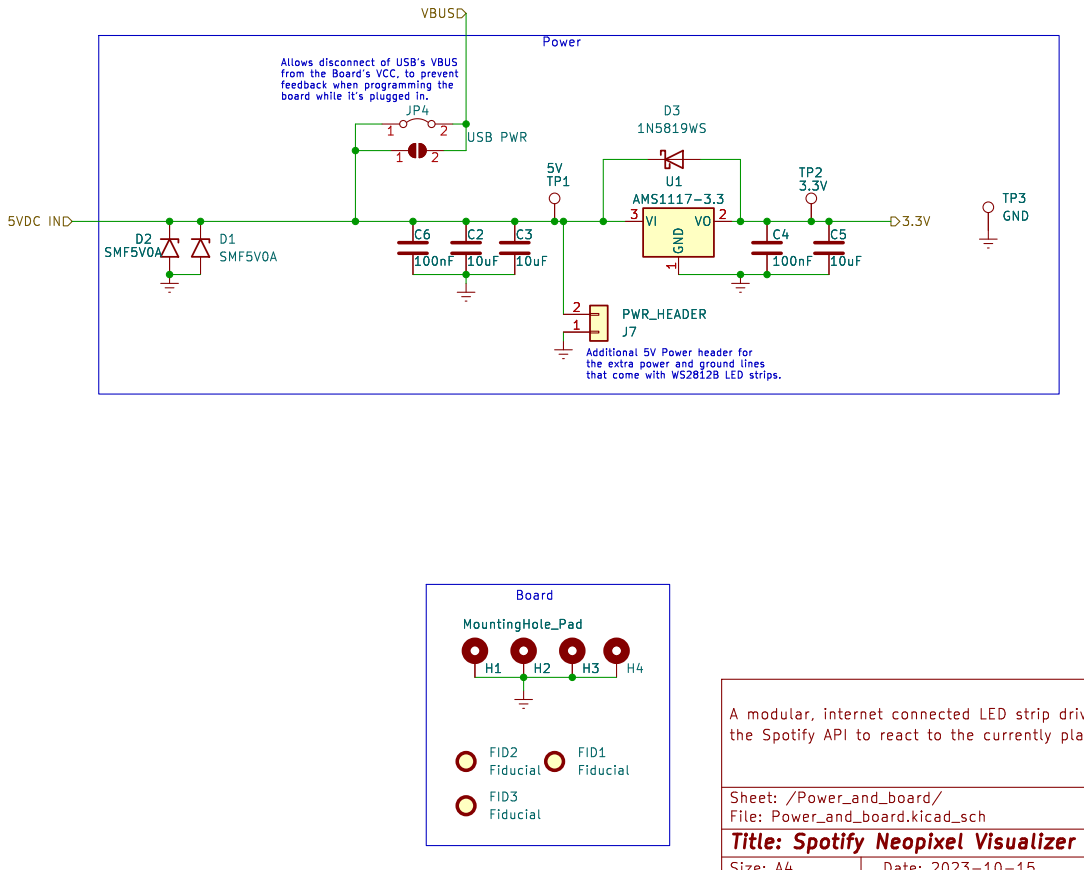
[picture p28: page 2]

the extra power and ground lines

Id: 2/2 Title: Spotify Neopixel Visualizer File: Power_and_board.kicad_sch Sheet: /Power_and_board/

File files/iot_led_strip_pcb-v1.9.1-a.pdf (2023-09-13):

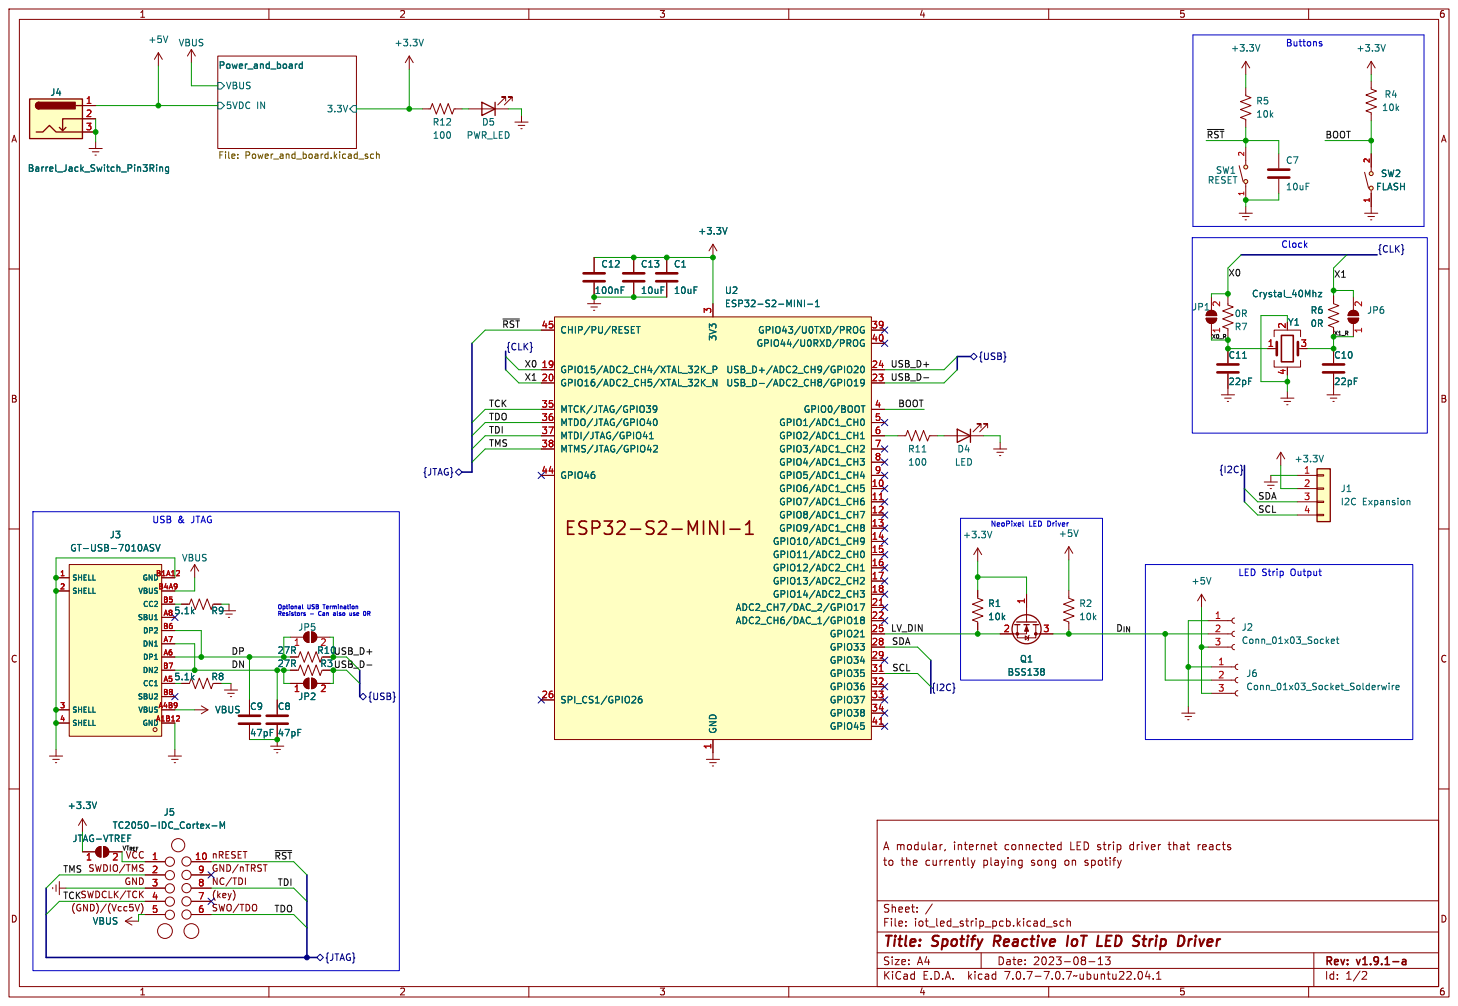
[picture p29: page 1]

3 GPIO35 31 GPIO36 32 GPIO37 33 GPIO38 34 MTCK/JTAG/GPIO39 35 MTDO/JTAG/GPIO40 36 MTDI/JTAG/GPIO41 37 MTMS/JTAG/GPIO42 38 GPIO43/U0TXD/PROG 39 GPIO0/BOOT 4 GPIO44/U0RXD/PROG 40 GPIO45 41 GPIO1/ADC1_CH0 5 GPIO2/ADC1_CH1 6 GPIO3/ADC1_CH2 7 GPIO4/ADC1_CH3 8 GPIO5/ADC1_CH4 9 +3.3V C1

3 GPIO35 31 GPIO36 32 GPIO37 33 GPIO38 34 MTCK/JTAG/GPIO39 35 MTDO/JTAG/GPIO40 36 MTDI/JTAG/GPIO41 37 MTMS/JTAG/GPIO42 38 GPIO43/U0TXD/PROG 39 GPIO0/BOOT 4 GPIO44/U0RXD/PROG 40 GPIO45 41 GPIO1/ADC1_CH0 5 GPIO2/ADC1_CH1 6 GPIO3/ADC1_CH2 7 GPIO4/ADC1_CH3 8 GPIO5/ADC1_CH4 9 U2ESP32-S2-MINI-1

Id: 1/2 Title: Spotify Reactive IoT LED Strip Driver File: iot_led_strip_pcb.kicad_sch Sheet: /

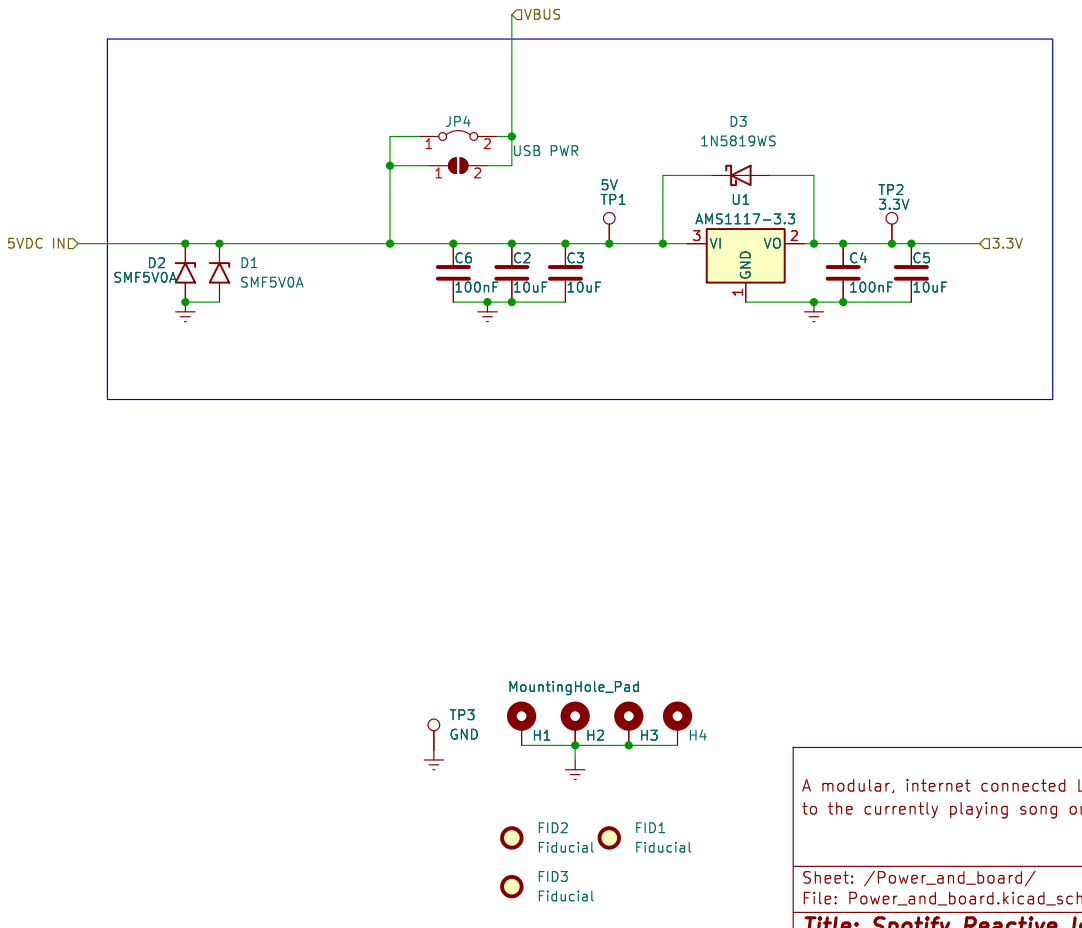
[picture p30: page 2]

Id: 2/2 Title: Spotify Reactive IoT LED Strip Driver File: Power_and_board.kicad_sch Sheet: /Power_and_board/

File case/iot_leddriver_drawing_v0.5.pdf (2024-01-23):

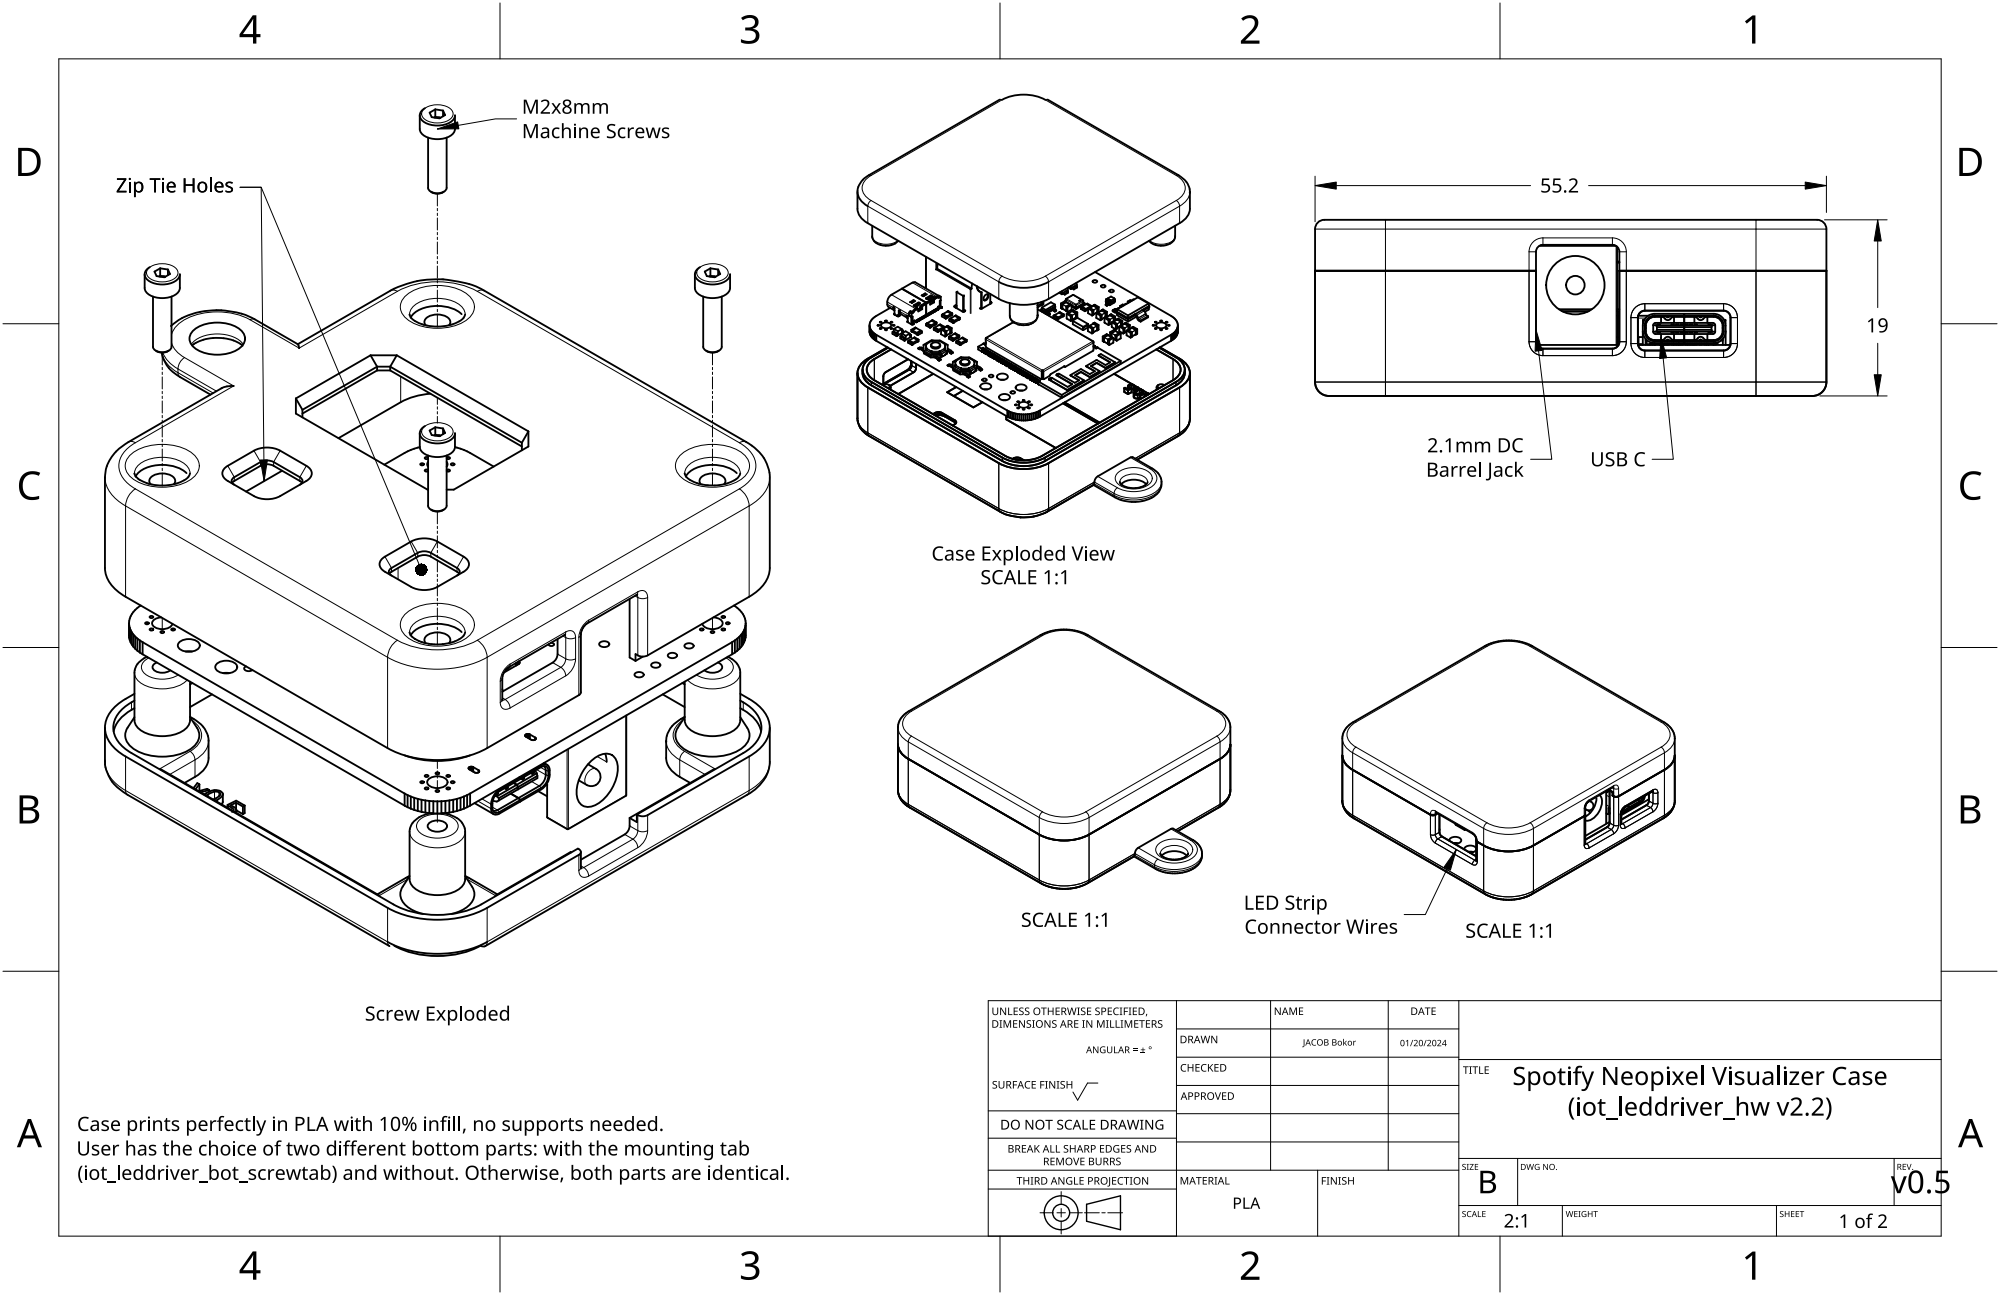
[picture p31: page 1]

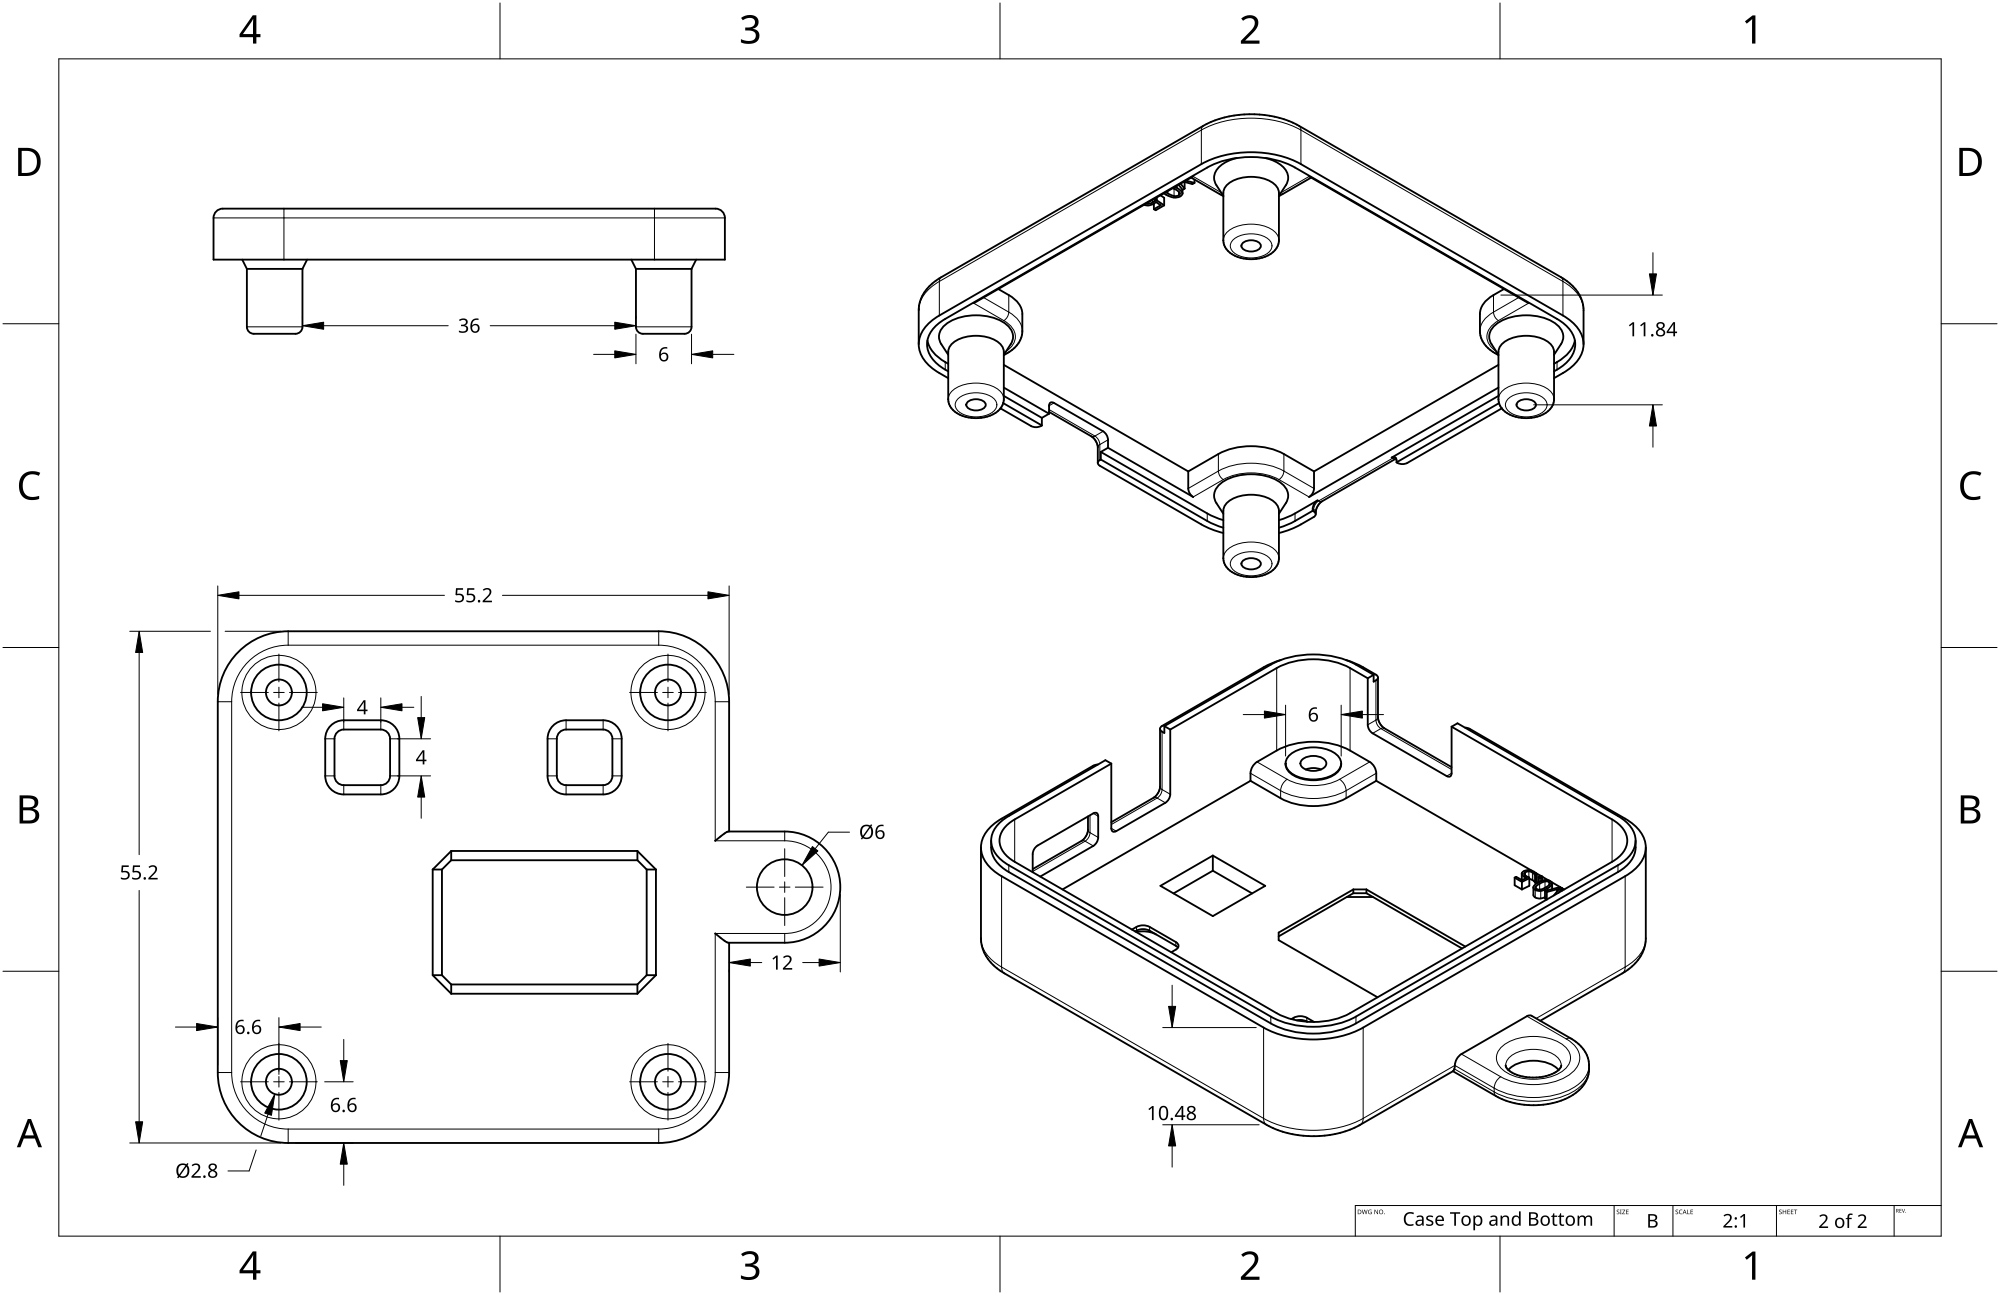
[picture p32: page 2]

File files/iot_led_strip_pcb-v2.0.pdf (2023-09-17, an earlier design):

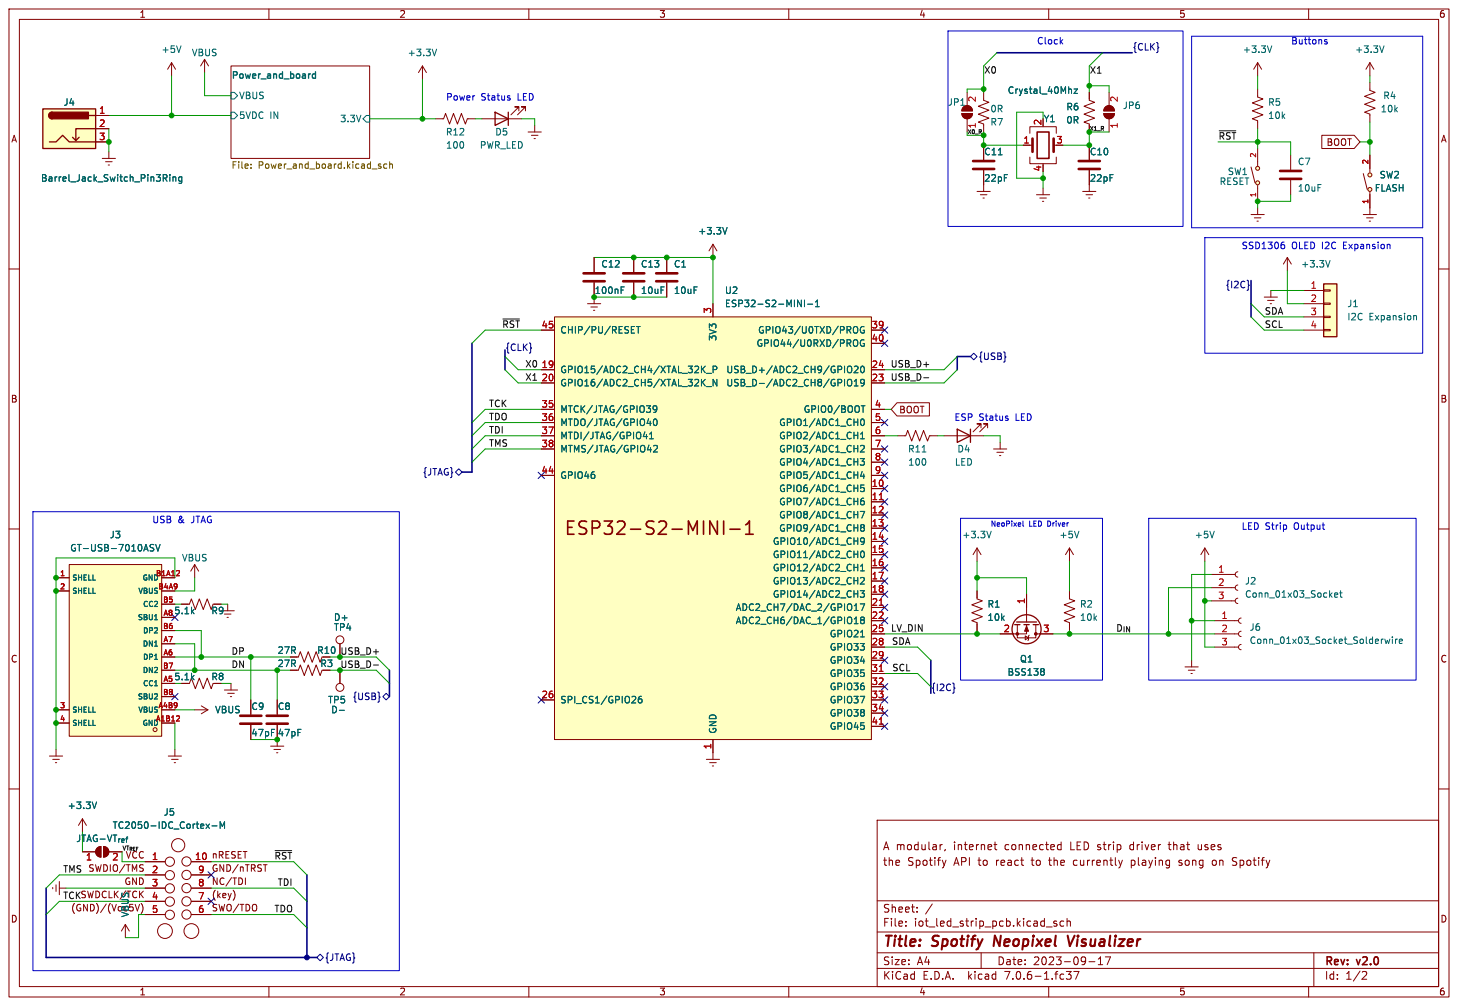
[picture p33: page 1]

LED Strip Output NeoPixel LED Driver Power Status LED

3 GPIO35 31 GPIO36 32 GPIO37 33 GPIO38 34 MTCK/JTAG/GPIO39 35 MTDO/JTAG/GPIO40 36 MTDI/JTAG/GPIO41 37 MTMS/JTAG/GPIO42 38 GPIO43/U0TXD/PROG 39 GPIO0/BOOT 4 GPIO44/U0RXD/PROG 40 GPIO45 41 GPIO1/ADC1_CH0 5 GPIO2/ADC1_CH1 6 GPIO3/ADC1_CH2 7 GPIO4/ADC1_CH3 8 GPIO5/ADC1_CH4 9 U2ESP32-S2-MINI-1

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

Id: 1/2 Title: Spotify Neopixel Visualizer File: iot_led_strip_pcb.kicad_sch Sheet: /

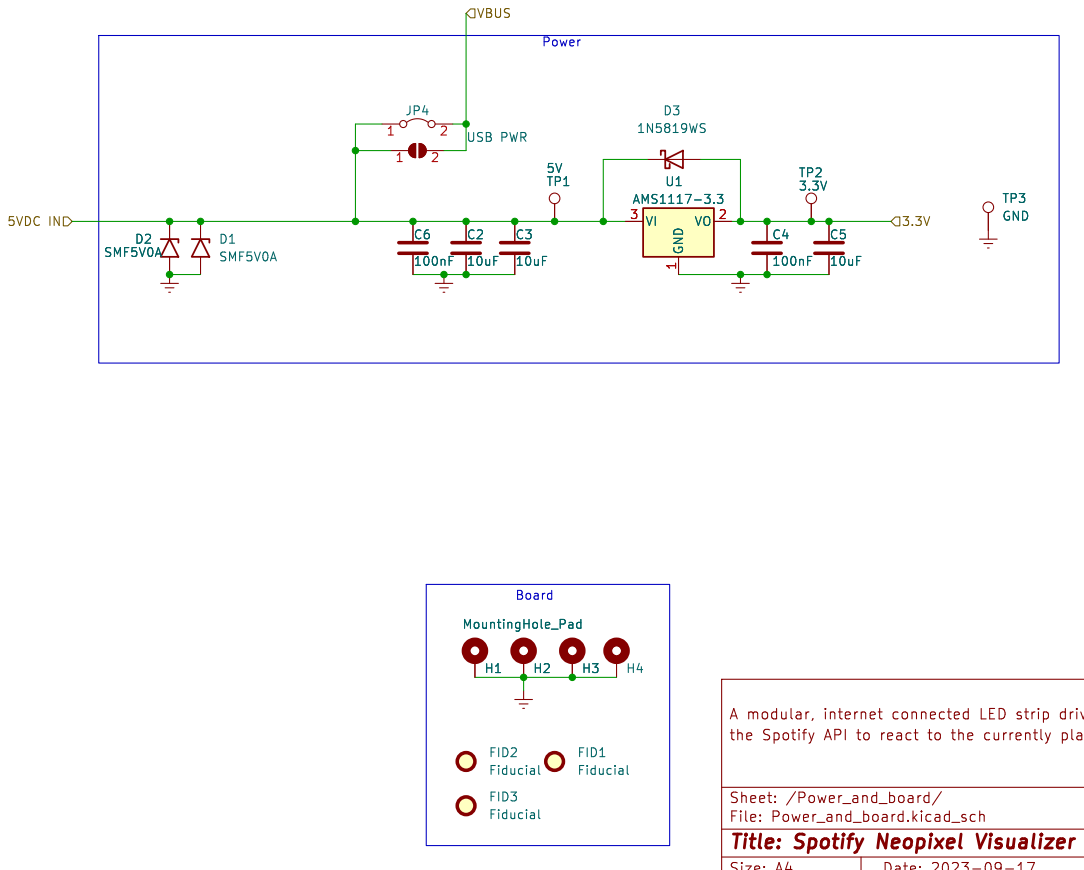
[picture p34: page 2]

Id: 2/2 Title: Spotify Neopixel Visualizer File: Power_and_board.kicad_sch Sheet: /Power_and_board/

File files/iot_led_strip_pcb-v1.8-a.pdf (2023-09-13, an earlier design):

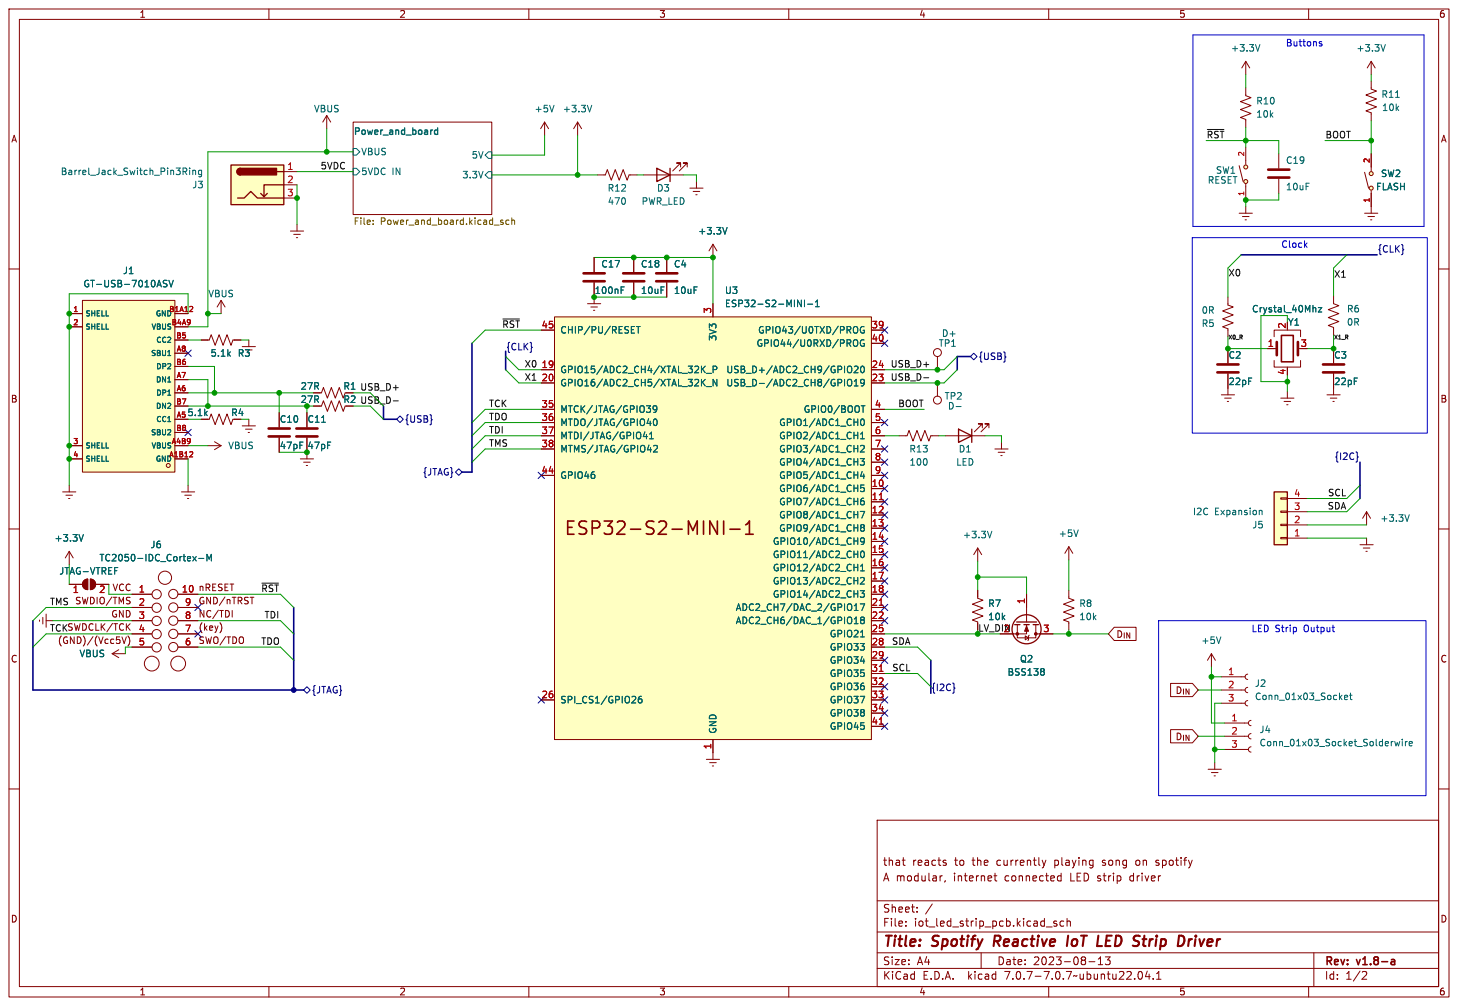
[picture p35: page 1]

{CLK} LED Strip Output Clock Buttons R7

1 2 SW1 RESET VBUS +5V ESP32-S2-MINI-1 GND

3 GPIO35 31 GPIO36 32 GPIO37 33 GPIO38 34 MTCK/JTAG/GPIO39 35 MTDO/JTAG/GPIO40 36 MTDI/JTAG/GPIO41 37 MTMS/JTAG/GPIO42 38 GPIO43/U0TXD/PROG 39 GPIO0/BOOT 4 GPIO44/U0RXD/PROG 40 GPIO45 41 GPIO1/ADC1_CH0 5 GPIO2/ADC1_CH1 6 GPIO3/ADC1_CH2 7 GPIO4/ADC1_CH3 8 GPIO5/ADC1_CH4 9 U3ESP32-S2-MINI-1 +3.3V

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

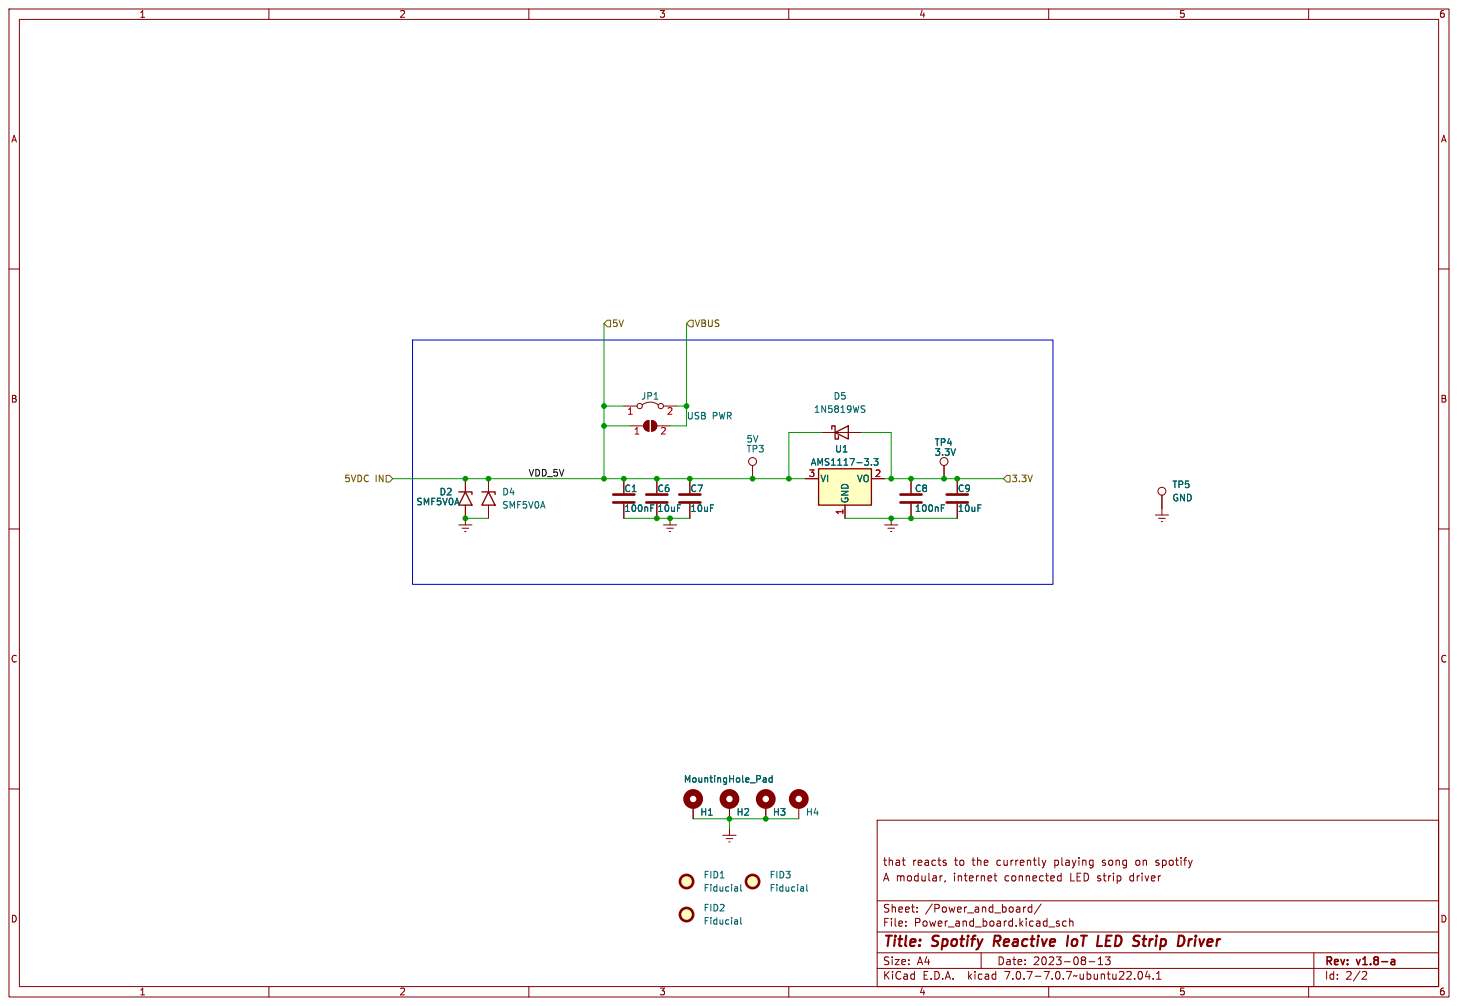
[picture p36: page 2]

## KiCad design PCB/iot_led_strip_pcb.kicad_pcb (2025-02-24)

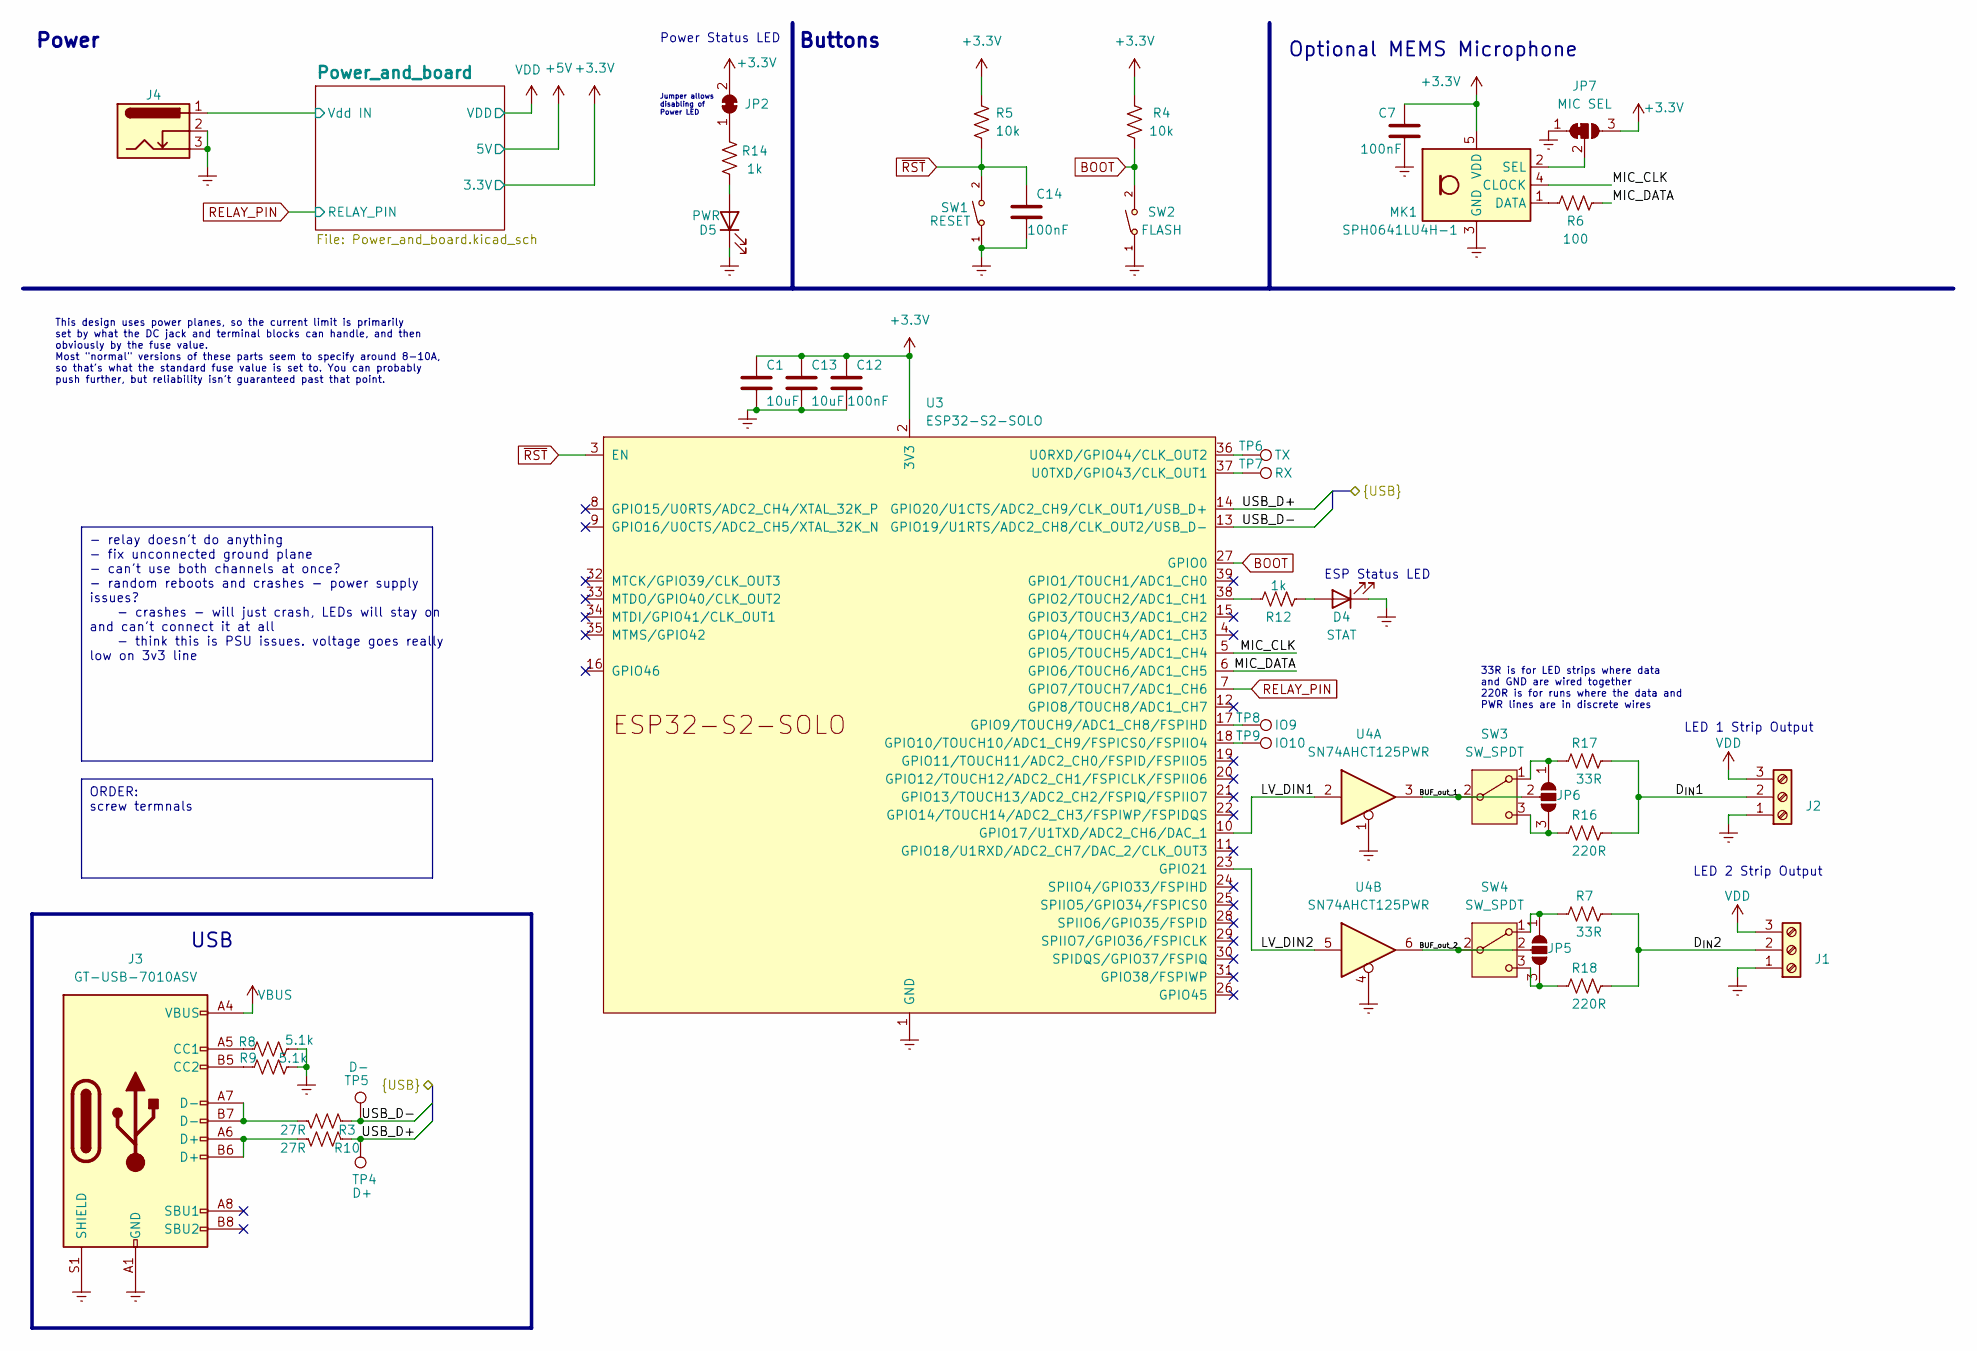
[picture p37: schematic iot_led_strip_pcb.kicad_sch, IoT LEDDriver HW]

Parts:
C1, C13: 10uF; C_0805_2012Metric_Pad1.18x1.45mm_HandSolder; LCSC C15850
C7, C12, C14: 100nF; C_0805_2012Metric_Pad1.18x1.45mm_HandSolder; LCSC C49678
D4: STAT; LED_0805_2012Metric_Pad1.15x1.40mm_HandSolder; LCSC C2297
D5: PWR; LED_0805_2012Metric_Pad1.15x1.40mm_HandSolder; LCSC C84256
J1, J2: Screw_Terminal_01x03; TerminalBlock_bornier-3_P5.08mm; LCSC C5188425
J3: GT-USB-7010ASV; USB-C-GT7010_FIXED; LCSC C2988369
J4: Barrel_Jack_Switch_Pin3Ring; BarrelJack_Wuerth_6941xx301002
JP2: PWR_LED_BRIDGE; SolderJumper-2_P1.3mm_Bridged_RoundedPad1.0x1.5mm
JP5, JP6: SolderJumper_3_Open; SolderJumper-3_P1.3mm_Open_Pad1.0x1.5mm
JP7: MIC SEL; SolderJumper-3_P1.3mm_Bridged12_RoundedPad1.0x1.5mm
MK1: SPH0641LU4H-1; Knowles_LGA-5_3.5x2.65mm; LCSC C5454543
R3, R10: 27R; R_0805_2012Metric_Pad1.20x1.40mm_HandSolder; LCSC C17594
R4, R5: 10k; R_0805_2012Metric_Pad1.20x1.40mm_HandSolder; LCSC C17414
R6: 100; R_0805_2012Metric_Pad1.20x1.40mm_HandSolder; LCSC C17408
R7, R17: 33R; R_0805_2012Metric_Pad1.20x1.40mm_HandSolder; LCSC C17634
R8, R9: 5.1k; R_0805_2012Metric_Pad1.20x1.40mm_HandSolder; LCSC C27834
R12, R14: 1k; R_0805_2012Metric_Pad1.20x1.40mm_HandSolder; LCSC C17513
R16, R18: 220R; R_0805_2012Metric_Pad1.20x1.40mm_HandSolder; LCSC C17557
SW1: RESET; SW_SPST_TL3342; LCSC C318884
SW2: FLASH; SW_SPST_TL3342; LCSC C318884
SW3, SW4: SW_SPDT; SW_SPDT_PCM12; LCSC C319020
TP4: D+; TestPoint_Pad_D1.5mm
TP5: D-; TestPoint_Pad_D1.5mm
TP6: TX; TestPoint_Pad_D1.5mm
TP7: RX; TestPoint_Pad_D1.5mm
TP8: IO9; TestPoint_Pad_D1.5mm
TP9: IO10; TestPoint_Pad_D1.5mm
U3: ESP32-S2-SOLO; LCSC C3040594
U4: SN74AHCT125PWR; TSSOP-14_4.4x5mm_P0.65mm; LCSC C36365

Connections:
+3.3V: C1.1, C7.1, C12.1, C13.1, JP2.2 (B), JP7.3 (B), MK1.5 (VDD), R4.2, R5.1, U3.2 (3V3); also elsewhere on the board
/BUF_out_1: JP6.2 (C), SW3.2 (B), U4.3
/BUF_out_2: JP5.2 (C), SW4.2 (B), U4.6
/D_{IN}1: J2.2, R16.2, R17.2
/D_{IN}2: J1.2, R7.2, R18.2
/LV_DIN1: U3.10 (GPIO17/U1TXD/ADC2_CH6/DAC_1), U4.2
/LV_DIN2: U3.23 (GPIO21), U4.5
/MIC_CLK: MK1.4 (CLOCK), U3.5 (GPIO5/TOUCH5/ADC1_CH4)
/MIC_DATA: R6.1, U3.6 (GPIO6/TOUCH6/ADC1_CH5)
/Power_and_board/Vdd IN: J4.1; also elsewhere on the board
/USB_D+: R10.2, TP4.1, U3.14 (GPIO20/U1CTS/ADC2_CH9/CLK_OUT1/USB_D+)
/USB_D-: R3.2, TP5.1, U3.13 (GPIO19/U1RTS/ADC2_CH8/CLK_OUT2/USB_D-)
BOOT: R4.1, SW2.2, U3.27 (GPIO0)
Earth: C1.2, C7.2, C12.2, C13.2, C14.2, D4.1 (K), D5.1 (K), J1.1, J2.1, J3.A1 (GND), J3.A12 (GND), J3.B1 (GND), J3.B12 (GND), J3.S1 (SHIELD), J4.2, J4.3, JP7.1 (A), MK1.3 (GND), R8.2, R9.1, SW1.1, SW2.1, U3.1 (GND), U3.40 (GND), U3.41 (GND), U4.1, U4.4; also elsewhere on the board
unnamed: D4.2 (A), R12.1
unnamed: D5.2 (A), R14.1
unnamed: J3.A5 (CC1), R8.1
unnamed: J3.B5 (CC2), R9.2
unnamed: J3.A6 (D+), J3.B6 (D+), R10.1
unnamed: J3.A7 (D-), J3.B7 (D-), R3.1
unnamed: JP2.1 (A), R14.2
unnamed: JP5.1 (A), R7.1, SW4.1 (A)
unnamed: JP5.3 (B), R18.1, SW4.3 (C)
unnamed: JP6.1 (A), R17.1, SW3.1 (A)
unnamed: JP6.3 (B), R16.1, SW3.3 (C)
unnamed: JP7.2 (C), MK1.2 (SEL)
unnamed: MK1.1 (DATA), R6.2
unnamed: R12.2, U3.38 (GPIO2/TOUCH2/ADC1_CH1)
unnamed: TP8.1, U3.17 (GPIO9/TOUCH9/ADC1_CH8/FSPIHD)
unnamed: TP9.1, U3.18 (GPIO10/TOUCH10/ADC1_CH9/FSPICS0/FSPIIO4)
unnamed: TP6.1, U3.36 (U0RXD/GPIO44/CLK_OUT2)
unnamed: TP7.1, U3.37 (U0TXD/GPIO43/CLK_OUT1)
RELAY_PIN: U3.7 (GPIO7/TOUCH7/ADC1_CH6); also elsewhere on the board
VBUS: J3.A4 (VBUS), J3.A9 (VBUS), J3.B4 (VBUS), J3.B9 (VBUS); also elsewhere on the board
VDD: J1.3, J2.3; also elsewhere on the board
~RST: C14.1, R5.2, SW1.2, U3.3 (EN)

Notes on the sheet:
ORDER: screw termnals
- relay doesn't do anything - fix unconnected ground plane - can't use both channels at once? - random reboots and crashes - power supply issues? - crashes - will just crash, LEDs will stay on and can't connect it at all - think this is PSU issues. voltage goes really low on 3v3 line
Power
Buttons
Jumper allows disabling of Power LED
33R is for LED strips where data and GND are wired together 220R is for runs where the data and PWR lines are in discrete wires
This design uses power planes, so the current limit is primarily set by what the DC jack and terminal blocks can handle, and then obviously by the fuse value. Most "normal" versions of these parts seem to specify around 8-10A, so that's what the standard fuse value is set to. You can probably push 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
LED 2 Strip Output
LED 1 Strip Output
ESP Status LED
Power Status LED
USB
Optional MEMS Microphone

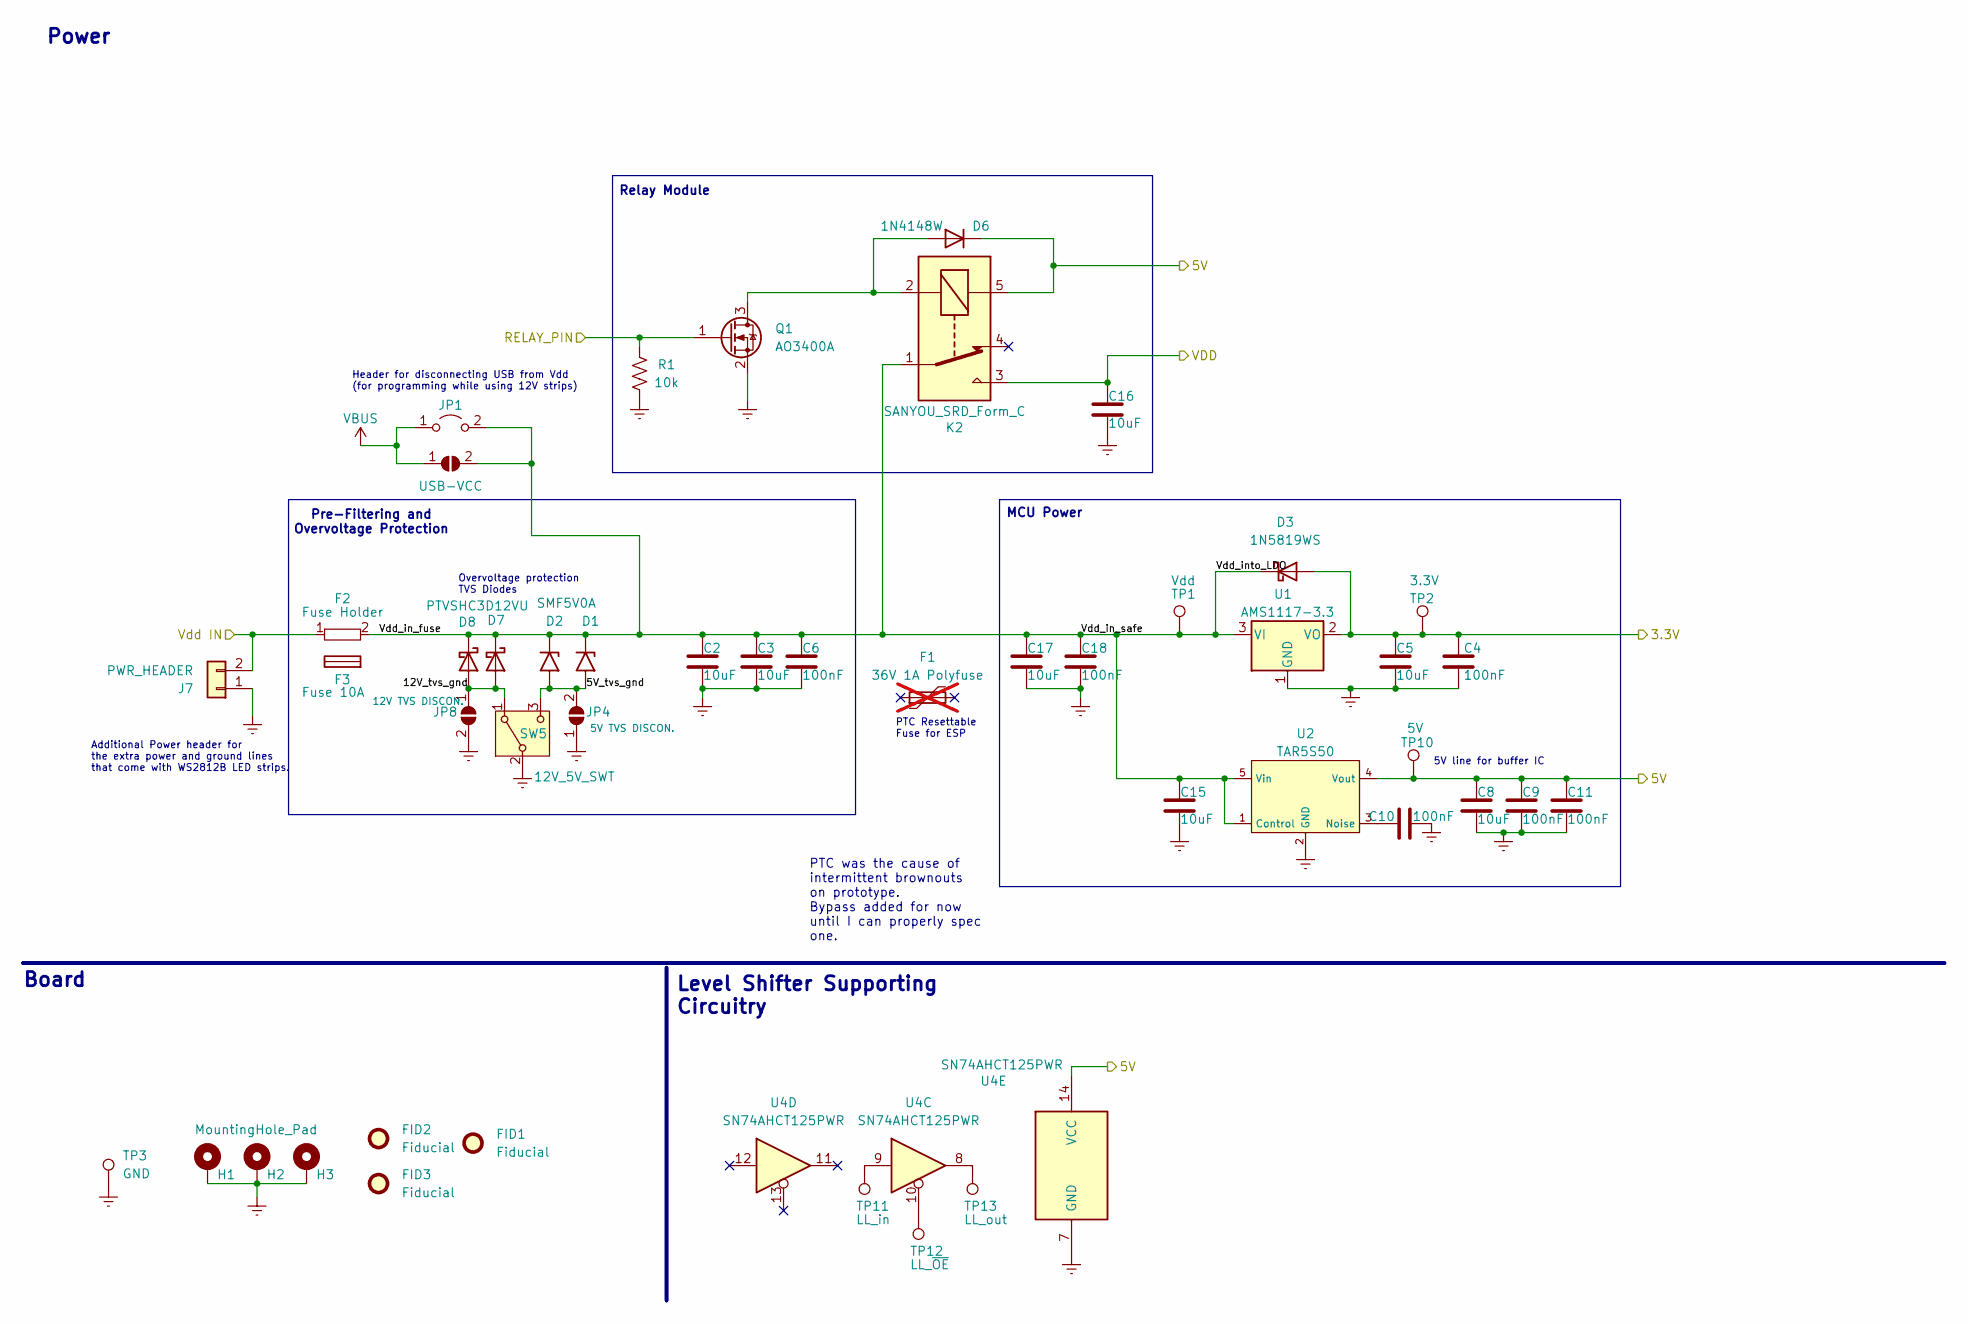
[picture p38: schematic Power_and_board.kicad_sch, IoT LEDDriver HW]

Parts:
C2, C3, C5, C8, C15, C16, C17: 10uF; C_0805_2012Metric_Pad1.18x1.45mm_HandSolder; LCSC C15850
C4, C6, C9, C10, C11, C18: 100nF; C_0805_2012Metric_Pad1.18x1.45mm_HandSolder; LCSC C49678
D1, D2: SMF5V0A; D_SMF; LCSC C1972946
D3: 1N5819WS; D_SOD-323_HandSoldering; LCSC C191023
D6: 1N4148W; D_SOD-123; LCSC C81598
D7, D8: PTVSHC3D12VU; D_SOD-323_HandSoldering; LCSC C169336
F1: 36V 1A Polyfuse; Fuse_1206_3216Metric_Pad1.42x1.75mm_HandSolder; LCSC C20616702; not fitted
F2: Fuse Holder; FUSE-TH_XF-505P; LCSC C843270
F3: Fuse 10A
FID1, FID2, FID3: Fiducial; Fiducial_0.5mm_Mask1mm
H1, H2, H3: MountingHole_Pad; MountingHole_2.2mm_M2_Pad_Via
J7: PWR_HEADER; SolderWire-0.5sqmm_1x02_P4.6mm_D0.9mm_OD2.1mm
JP1: USB-VDD; TestPoint_2Pads_Pitch2.54mm_Drill0.8mm
JP3: USB-VCC; SolderJumper-2_P1.3mm_Open_RoundedPad1.0x1.5mm
JP4: 5V TVS DISCON.; SolderJumper-2_P1.3mm_Open_RoundedPad1.0x1.5mm
JP8: 12V TVS DISCON.; SolderJumper-2_P1.3mm_Open_RoundedPad1.0x1.5mm
K2: SANYOU_SRD_Form_C; Relay_SPDT_SANYOU_SRD_Series_Form_C; LCSC C35449
Q1: AO3400A; SOT-23_Handsoldering; LCSC C20917
R1: 10k; R_0805_2012Metric_Pad1.20x1.40mm_HandSolder; LCSC C17414
SW5: 12V_5V_SWT; SW_SPDT_PCM12; LCSC C319020
TP1: Vdd; TestPoint_Pad_D1.5mm
TP2: 3.3V; TestPoint_Pad_D1.5mm
TP3: GND; TestPoint_Pad_D1.5mm
TP10: 5V; TestPoint_Pad_D1.5mm
TP11: LL_in; TestPoint_Pad_D1.0mm
TP12: LL_~{OE}; TestPoint_Pad_D1.0mm
TP13: LL_out; TestPoint_Pad_D1.0mm
U1: AMS1117-3.3; SOT-223-3_TabPin2; LCSC C6186
U2: TAR5S50; SSOP-5_L2.9-W1.6-P0.95-LS2.8-TL; LCSC C146354
U4: SN74AHCT125PWR; TSSOP-14_4.4x5mm_P0.65mm; LCSC C36365

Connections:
+3.3V: C4.1, C5.1, D3.2 (A), TP2.1, U1.2 (VO); also elsewhere on the board
+5V: C8.1, C9.1, C11.1, D6.1 (K), K2.5, TP10.1, U2.4 (Vout), U4.14 (VCC)
/Power_and_board/5V_tvs_gnd: D1.2 (A2), D2.2 (A2), JP4.2 (B), SW5.3 (C)
/Power_and_board/12V_tvs_gnd: D7.2 (A), D8.2 (A), JP8.1 (A), SW5.1 (A)
/Power_and_board/Vdd IN: F2.1, J7.2; also elsewhere on the board
/Power_and_board/Vdd_in_fuse: C2.1, C3.1, C6.1, C15.1, C17.1, C18.1, D1.1 (A1), D2.1 (A1), D3.1 (K), D7.1 (K), D8.1 (K), F2.2, JP1.2 (B), JP3.2 (B), K2.1, TP1.1, U1.3 (VI), U2.1 (Control), U2.5 (Vin)
Earth: C2.2, C3.2, C4.2, C5.2, C6.2, C8.2, C9.2, C10.2, C11.2, C15.2, C16.2, C17.2, C18.2, H1.1, H2.1, H3.1, J7.1, JP4.1 (A), JP8.2 (B), Q1.2 (S), R1.1, SW5.2 (B), TP3.1, U1.1 (GND), U2.2 (GND), U4.7 (GND); also elsewhere on the board
unnamed: D6.2 (A), K2.2, Q1.3 (D)
unnamed: TP11.1, U4.9
unnamed: TP12.1, U4.10
unnamed: TP13.1, U4.8
unnamed: C10.1, U2.3 (Noise)
RELAY_PIN: Q1.1 (G), R1.2; also elsewhere on the board
VBUS: JP1.1 (A), JP3.1 (A); also elsewhere on the board
VDD: C16.1, K2.3; also elsewhere on the board

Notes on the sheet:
PTC was the cause of intermittent brownouts on prototype. Bypass added for now until I can properly spec one.
5V line for buffer IC
Overvoltage protection TVS Diodes
Relay Module
MCU Power
Header for disconnecting USB from Vdd (for programming while using 12V strips)
Pre-Filtering and Overvoltage Protection
PTC Resettable Fuse for ESP
Board
Additional Power header for the extra power and ground lines that come with WS2812B LED strips.
Power
Level Shifter Supporting Circuitry

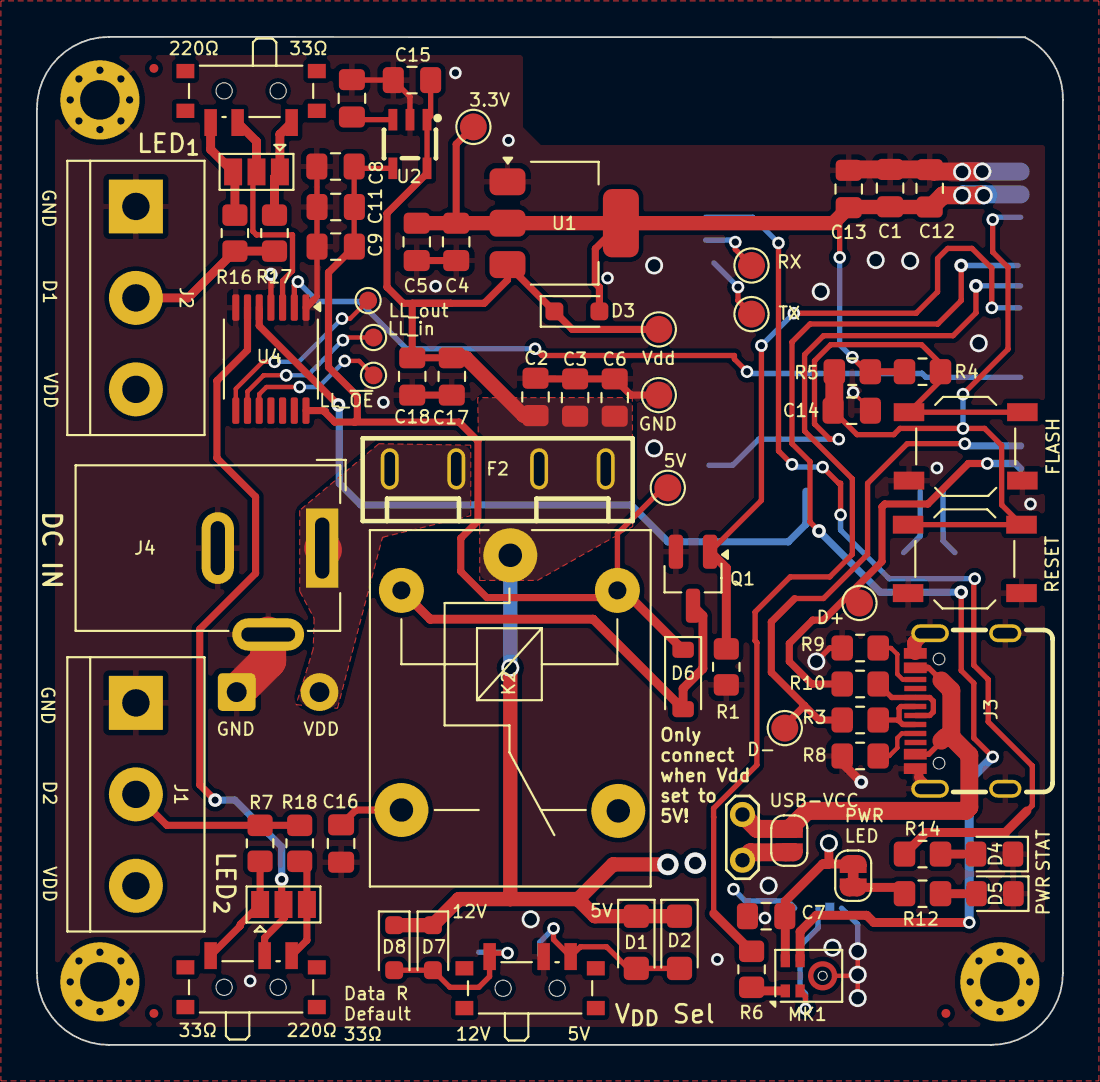
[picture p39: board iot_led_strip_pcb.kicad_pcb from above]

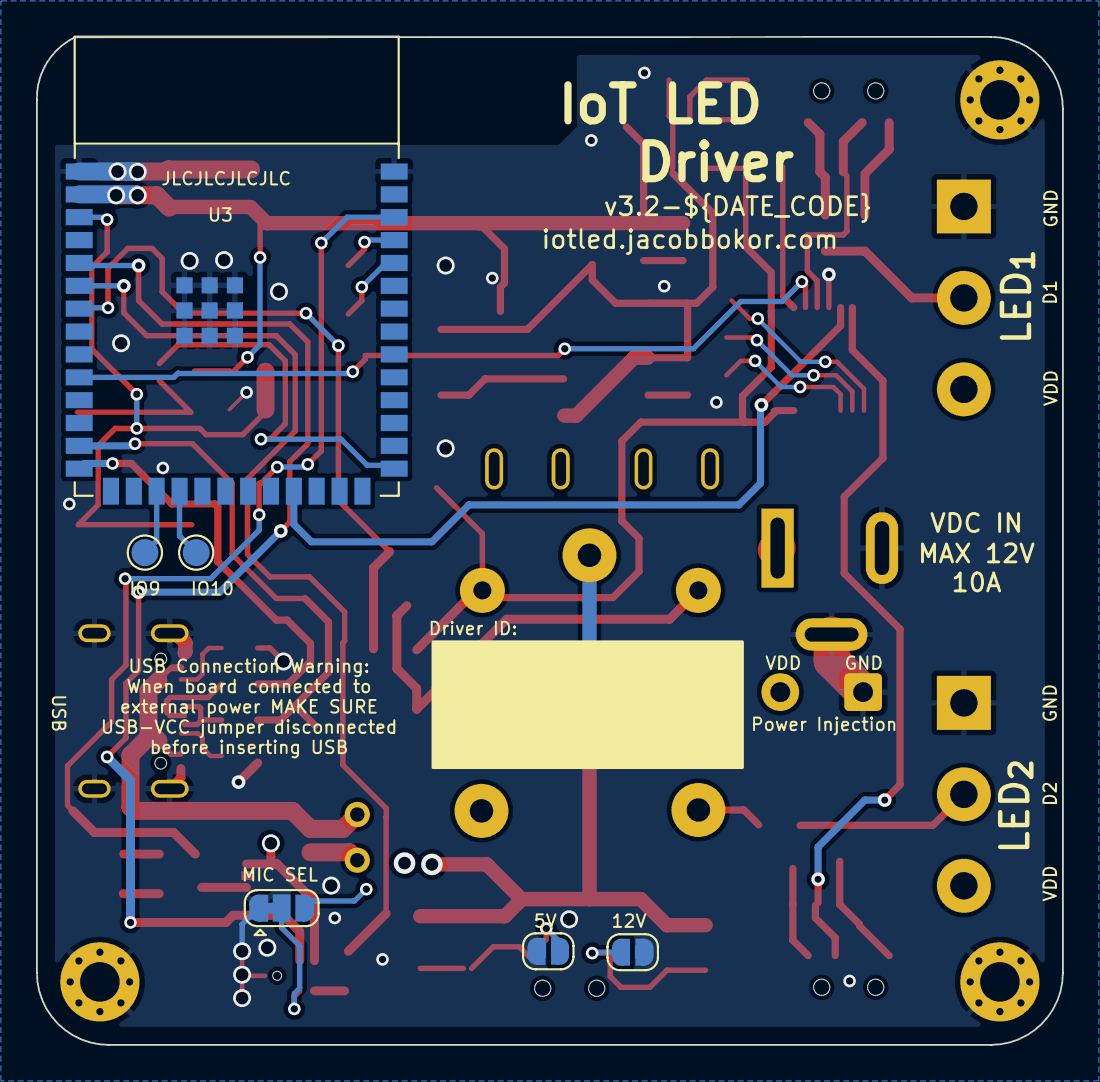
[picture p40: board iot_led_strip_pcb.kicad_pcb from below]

Board: 4 copper layers, 57.0 x 56.0 mm, 85 parts (6 on the bottom side), 45 nets.

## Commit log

2023-08-04 initial rev of design
    [LED_driver.kicad_sch, Power_and_board.kicad_sch, USB_to_Serial.kicad_sch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]
2023-08-09 initial layout rev 0.1
    [iot_led_strip_pcb.kicad_pcb]
2023-08-13 replaced all vias, reworked traces, DRC passes now
    [LED_driver.kicad_sch, Power_and_board.kicad_sch, USB_to_Serial.kicad_sch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]
2023-08-13 upgrade to kicad 7, some changes to pcb text
    [iot_led_strip_pcb.kicad_pcb]
2023-08-14 updated text, finalizing of board design, updated schematic rev number
    [LED_driver.kicad_sch, Power_and_board.kicad_sch, USB_to_Serial.kicad_sch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]
2023-08-15 production files
    [bom.csv, designators.csv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]
2023-09-12 library changes, fixed model for dc jack
    [LED_driver.kicad_sch, Power_and_board.kicad_sch, USB_to_Serial.kicad_sch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]
2023-09-12 some cleanup
    [bom.csv, designators.csv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]
2023-09-13 started work on new schematic
    [Power_and_board.kicad_sch, iot_led_strip_pcb.kicad_sch]
2023-09-13 schematic v1.9 initial rev
    [Display_SRs.kicad_sch, LED_driver.kicad_sch, Optional_HW.kicad_sch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]
2023-09-13 some small changes to schematic, cleaned up old pcb
    [Power_and_board.kicad_sch, iot_led_strip_pcb.csv, iot_led_strip_pcb.kicad_pcb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]
2023-09-13 did layout, whoops
    [Power_and_board.kicad_sch, iot_led_strip_pcb.kicad_pcb, iot_led_strip_pcb.kicad_sch]
2023-09-13 renamed schematic
2023-09-13 added photos of v2 prototype and updated readme
    [iot_led_strip_pcb.kicad_pcb]
2023-09-13 moved one thing i think
    [iot_led_strip_pcb.kicad_sch]
2023-09-14 some minor cleanup of schematic and layout
    [Power_and_board.kicad_sch, iot_led_strip_pcb.kicad_pcb, iot_led_strip_pcb.kicad_sch]
2023-09-16 organized schematic & added bom
    [Power_and_board.kicad_sch, iot_led_strip_pcb.csv, iot_led_strip_pcb.kicad_sch]
2023-09-17 final modifications, cleanup, added v2.0 photos as ordered
    [Power_and_board.kicad_sch, iot_led_strip_pcb.csv, iot_led_strip_pcb.kicad_pcb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]
2023-09-26 Moved button labels and multiple minor modifications
    * Implemented Orion's suggestion for replacing 10uF cap on reset button
    with 100nF.
    * Moved silkscreen for both buttons underneath and moved jtag label.
    * Added labels to both power and status LEDs.
    [Power_and_board.kicad_sch, iot_led_strip_pcb.kicad_pcb, iot_led_strip_pcb.kicad_sch]
2023-09-29 some pcb changes and update to readme
    [iot_led_strip_pcb.kicad_pcb]
2023-10-02 small modifications + RT render
    [iot_led_strip_pcb.kicad_pcb, iot_led_strip_pcb.kicad_sch]
2023-10-03 PCBA today - field edits on Cs, Rs, removed Rs on Y1
    [iot_led_strip_pcb.kicad_pcb, iot_led_strip_pcb.kicad_sch]
2023-10-05 modified sch to change over to esp32-s2-solo-2, should be much easier to solder
    [iot_led_strip_pcb.kicad_pcb, iot_led_strip_pcb.kicad_sch]
2023-10-06 board redesign around ESP32-S2-SOLO-2
    [iot_led_strip_pcb.kicad_pcb, iot_led_strip_pcb.kicad_sch]
2023-10-16 lots of small changes. Schematic updated with mic, layout not yet
    [Power_and_board.kicad_sch, iot_led_strip_pcb.kicad_pcb, iot_led_strip_pcb.kicad_sch]
2023-10-16 microphone added to layout, DRC passes
    [iot_led_strip_pcb.kicad_pcb, iot_led_strip_pcb.kicad_sch]
2023-10-16 v2.1 export, renders
    [Power_and_board.kicad_sch, iot_led_strip_pcb.kicad_pcb, iot_led_strip_pcb.kicad_sch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]
2023-10-16 replaced crystal. re-updated all renders and images
    [iot_led_strip_pcb.kicad_pcb, iot_led_strip_pcb.kicad_sch, iot_leddriver_v2.1_BOM.csv]
2023-10-16 re-re-updated photos & board
    [iot_led_strip_pcb.kicad_pcb]
2023-10-29 some minor changes from during assembly and gif of assembled board added
    [iot_led_strip_pcb.kicad_pcb, iot_led_strip_pcb.kicad_sch]
2023-11-05 added power led disconnect and cleaned up some traces
    [Power_and_board.kicad_sch, iot_led_strip_pcb.kicad_pcb, iot_led_strip_pcb.kicad_sch]
2023-11-05 moved i2c SCL to pin on both S2 and S3
    [iot_led_strip_pcb.kicad_pcb, iot_led_strip_pcb.kicad_sch]
2023-11-05 label and some mini changes
    [iot_led_strip_pcb.kicad_pcb]
2023-11-06 v2.2 as ordered
    [iot_led_strip_pcb.kicad_pcb, iot_led_strip_pcb.kicad_sch]
2023-11-14 added screenshots, files, updated readme for v2.2, sch & layout cleanup
    [iot_led_strip_pcb.kicad_pcb, iot_led_strip_pcb.kicad_sch]
2023-11-14 higher res board renders
2023-11-15 added box to silkscreen for writing device name
    [iot_led_strip_pcb.kicad_pcb]
2023-12-17 modifications before workstation change
    [iot_led_strip_pcb.kicad_pcb]
2024-01-23 added data line resistor and other small changes
    [Power_and_board.kicad_sch, iot_led_strip_pcb.kicad_pcb, iot_led_strip_pcb.kicad_sch]
2024-01-23 added case compatible with v2.0+
    [Power_and_board.kicad_sch, iot_led_strip_pcb.kicad_pcb, iot_led_strip_pcb.kicad_sch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]
2024-01-23 updated readme and added case readme
2024-02-23 Major schematic update for v2.3
    This was my first real PCB project, and looking back with a couple
    months of hindsight I made some mistakes. Some best practices for
    driving WS2812B strips weren't followed in my original version, and
    I've updated the schematic to reflect what I've learned and what
    improvements needed to be made.
    * Warning added to README about current version
    * Schematic reorganized into tiles
    * RTC clock removed
    * OLED and I2C headers removed
    * JTAG footprint updated
    * Pin header output replaced with screw terminal
    * Hole size for power injection header increased
    * Added whole system fuse and PTC fuse to protect ESP32
    * Added reverse polarity protection and re-added ability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
    [Power_and_board.kicad_sch, iot_led_strip_pcb.kicad_pcb, iot_led_strip_pcb.kicad_sch]
2024-04-11 Schematic and Board redesigned for new rev: v3.0
    Schematic and board redone for next generation board - v3.0. Current rev is v3.0b.
    * pin numbers added to PCB
    * Silkscreen spot for writing board identifier in sharpie
    * Silkscreen updated with more detailed information about board and pins to improve UX
    * Logic level converters still present on data lines
    * Selectable data line resistors added
    * Moved to screw terminals instead of requiring soldered on connectors
    * Logic level shifter IC - 74AHCT125 - Added. Two channels in use, one broken out to pads.
    * System blade fuse added, along with PTC fuse for ESP itself.
    * selectable board voltage - 5 or 12V
    * Power inejction headers upgraded - b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
    [Power_and_board.kicad_sch, iot_led_strip_pcb.kicad_sch]
2025-02-24 v3.2 changes
    * Removed PTC fuse, since that caused issues on the last one
    * Other minor changes (that i've forgotten)
    [Power_and_board.kicad_sch, iot_led_strip_pcb.kicad_pcb, iot_led_strip_pcb.kicad_sch]
